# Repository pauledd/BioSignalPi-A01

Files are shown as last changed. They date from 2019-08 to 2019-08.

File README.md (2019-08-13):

# BioSignalPi-A01

Eagle files for the BioSignalPi-A01 egc prototype.  
For application software look at http://martinr89.github.io/BiosignalPI  

NCSA Image

Biosignal PI is licensed by Farhad Abtahi under a Creative Commons Attribution-NonCommercial-ShareAlike 4.0 International License. You are free to:  
    
    Share — copy and redistribute the material in any medium or format
    Adapt — remix, transform, and build upon the material

The licensor cannot revoke these freedoms as long as you follow the license terms.
Under the following terms:

Attribution — You must give appropriate credit, provide a link to the license, and indicate if changes were made. You may do so in any reasonable manner, but not in any way that suggests the licensor endorses you or your use.  
What does "Attribute this work" mean?  
The page you came from contained embedded licensing metadata, including how the creator wishes to be attributed for re-use. You can use the HTML here to cite the work. Doing so will also include metadata on your page so that others can find the original work as well.  

    NonCommercial — You may not use the material for commercial purposes.

    ShareAlike — If you remix, transform, or build upon the material, you must distribute your contributions under the same license as the original.

    No additional restrictions — You may not apply legal terms or technological measures that legally restrict others from doing anything the license permits.

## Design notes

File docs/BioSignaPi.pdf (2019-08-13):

# Software development of Biosignal Pi

An affordable opensource platform for monitoring ECG and respiration

J O N A T A N S N Ä L L

Master of Science Thesis in Medical Engineering Stockholm 2014

II

Software development of Biosignal Pi
An affordable open source platform for monitoring ECG and respiration

Utveckling av mjukvara till Biosignal Pi
En open-source plattform för övervakning av EKG och andning

J O N A T A N S N Ä L L

Master of Science Thesis in Medical Engineering Advanced level (second cycle), 30 credits Supervisor at KTH: Farhad Abtahi Examiner: Mats Nilsson
School of Technology and Health TRITA-STH. EX 2014:100

Royal Institute of Technology KTH STH
SE-141 86 Flemingsberg, Sweden http://www.kth.se/sth

IV

V

Examensarbete inom medicinsk

teknik (HL202X) 30hp

Software development of Biosignal Pi
Technology and Health
Jonatan Snäll
Godkänt 2014-09-30 | Recensent Prof. Kaj Lindecrantz | Handledare Farhad Abtahi
| Uppdragsgivare Dr. Mats Nilsson

## Sammanfattning

För att hantera den ökande kostnaden för hälso- och sjukvård kommer en större del av övervakning samt vård att ske i patientens hem. Det kommer därför att vara önskvärt att utveckla mindre system som är lättare att hantera än de större traditionella apparaterna för att samla in vanliga biosignaler som exempelvis ett EKG.

Detta projekt är en fortsättning på ett tidigare projekt vars syfte var att framställa en ”sköld” som kan kopplas ihop med en Raspberry Pi via dess GPIO pinnar. Det föregående projektet var lyckat och en sköld innehållande en ADAS1000 som kan samla in bl.a. ett EKG samt andningen framställdes.

Syftet med detta projekt var att utveckla en applikation som kan köras på en Raspberry Pi och på så sätt visa den data som samlas in från skölden på en skärm. Det skulle även vara möjligt att spara insamlad data för senare användning. Projektet resulterade i en applikation som uppfyllde dessa krav.

Nyckelord: Raspberry Pi, ADAS1000, Biosignal Pi, EKG

VII

Master of Science Thesis in Medical Engineering (HL202X) 30 credits

Software development of Biosignal Pi
Technology and Health
Jonatan Snäll
Approved 2014-09-30 | Reviewer Prof. Kaj Lindecrantz | Supervisor Farhad Abtahi
| Examiner Dr. Mats Nilsson

## Abstract

In order to handle the increasing costs of healthcare more of the care and monitoring will take place in the patient’s home. It is therefore desirable to develop smaller and portable systems that can record important biosignals such as the electrical activity of the heart in the form of an ECG.

This project is a continuation on a previous project that developed a shield that can be connected to the GPIO pins of a Raspberry Pi, a credit-card sized computer. The shield contains an ADAS1000, a low power and compact device that can record the electrical activity of the heart along with respiration.

The aim of this project was to develop an application that can run on the Raspberry Pi in order to display the captured data from the shield on a screen along with storing the data for further processing. The project was successful in the way that the requirements for the software have been fulfilled.

Keywords: Raspberry Pi, ADAS1000, Biosignal Pi, ECG

IX

## ACKNOWLEDGEMENT

First and foremost I would like to thank my supervisor Farhad Abtahi for the support and guidance throughout the whole project.

I would also like to thank my fellow students Klara Lindskog, Niklas Roos, Lucas Dizon, Martin Johansson and Jing Wang for the constructive discussions during our meetings and for sharing ideas.

I would also like to thank my family for their support and believing in me.

Jonatan Snäll

Stockholm, August 2014

XI

## NOMENCLATURE

## Abbreviations

ADAS | The ADAS 1000 chip
ECG | Electrocardiogram
EDF | European Data Format
GPIO | General Purpose Input/Output
GUI | Graphical User Interface
RLD | Right Leg Drive
RPI | Raspberry Pi
SoC | System On Chip
SPI | Serial Peripheral Interface

XIII

## TABLE OF CONTENTS

ACKNOWLEDGEMENT__________________________________________________________IX NOMENCLATURE______________________________________________________________XI TABLE OF CONTENTS _________________________________________________________XIII

### 1 INTRODUCTION _____________________________________________________________ 1

### 1.1 Background____________________________________________________________________ 1

### 1.2 Objective______________________________________________________________________ 1

### 1.3 Outline _______________________________________________________________________ 2

### 2 THEORETICAL FRAMEWORKS __________________________________________________ 3

### 2.1 Electrophysiology of the heart_____________________________________________________ 3

### 2.2 Raspberry Pi ___________________________________________________________________ 5

### 2.3 GPIO and SPI___________________________________________________________________ 6

### 2.4 ADAS1000 _____________________________________________________________________ 7

### 2.5 Qt Framework__________________________________________________________________ 8

2.5.1 Signals and slots ______________________________________________________________________ 9 2.5.2 Multithreading in Qt__________________________________________________________________ 10

### 2.6 Cross compiling________________________________________________________________ 11

### 2.7 Iterative development __________________________________________________________ 11

### 2.8 European Data Format__________________________________________________________ 12

### 3 METHODS_________________________________________________________________ 15

### 3.1 Requirements and technical goals_________________________________________________ 15

### 3.2 GUI development ______________________________________________________________ 16

### 3.3 Interfacing with the ADAS _______________________________________________________ 16

### 3.4 Data capture__________________________________________________________________ 18

### 3.5 Communication between threads _________________________________________________ 19

### 3.6 Data plotting__________________________________________________________________ 21

### 3.7 Data storage __________________________________________________________________ 24

### 4 RESULTS __________________________________________________________________ 25

### 4.1 Overview of the application______________________________________________________ 25

### 4.2 The ECG capture widget_________________________________________________________ 26

### 4.3 The ECG view widget ___________________________________________________________ 28

### 5 DISCUSSION _______________________________________________________________ 31

5.1 Discussion of the produced application ____________________________________________ 31

5.2 Ethical aspects of using the application ____________________________________________ 32

### 6 CONCLUSIONS _____________________________________________________________ 33

XIV

### 7 FUTURE WORK_____________________________________________________________ 35

### 7.1 Additional features_____________________________________________________________ 35

### 7.2 Future work __________________________________________________________________ 35

### 8 EXPERIENCE GAINED ________________________________________________________ 37

REFERENCES _____________________________________________________________ 39

## 1 INTRODUCTION

### 1.1 Background

An ageing population is an obvious phenomenon in most of the world. An increasing percentage of elderly in the population is mainly caused by a longer life expectancy and lowered fertility rates. Due to the increased percentage of the elderly, higher costs for the healthcare follows [1]. In order to tackle the increasing costs more of the care and monitoring will be performed in the caretaker’s home, this is an increasing trend which will be more common in the future. [2] According to Stockholm country council (SLL) care in the patient’s home is one of their development areas and that it is seen as positive by the patient to receive care outside of the hospital area. [3]

Homecare is usually involving monitoring of the patient and with the current technology a vast number of bio-signals can be measured, such as the hearts electrical activity in the form of an ECG. Due to increasing costs of healthcare and the fact that more of the patient monitoring will take place in the patients home, a low cost and portable system would be desirable. The ADAS1000 (ADAS) is a small and affordable device featuring five-lead ECG digital conversion, lead-off detection and respiration. The ADAS combined with the Raspberry Pi (RPI) which is a small, yet powerful computer, could be an affordable solution.

This project will be a continuation of a previous project that focused on the hardware part, images on the system built in the previous project can be found in appendix C. The conclusions and suggestions for future projects were that the ADAS is a suitable device and that it is possible to connect to the RPI but that the processing power of the RPI was low, thus making it hard to visualize the data in real-time. [4]

### 1.2 Objective

The purpose of this work was to create software running on the RPI that can collect and visualize the biosignals collected from the ADAS.

The goal of this project was:

- Create a way to communicate with existing hardware in order to collect the appropriate bio-signals.
- Visualize collected data in “real-time”
- Store visualized data for further processing later on
- Playback collected data
- Create a suitable graphical user interface (GUI) that can run on the RPI
- Optimum usage of resources considering limited resources of the RPI

### 1.3 Outline

The theoretical framework for the work is presented in chapter 2, followed by the methods used to get the final software in chapter 3. In chapter 4, the results of the work are summarized. Chapter 5 is a discussion where the work will be evaluated. Conclusions from the project are described in chapter 6. Finally, suggestions for future work are presented in chapter 7.

## 2 THEORETICAL FRAMEWORKS

### 2.1 Electrophysiology of the heart

The heart is the primary part of the circulatory system in the human body. The circulatory system consists of three parts, namely, pulmonary circulation, coronary circulation and systemic circulation. The heart acts as a pump, regulating the flow of blood by contracting at different rates. Circulating blood through this system has three main purposes; transportation (e.g. oxygen to the cells, carbon dioxide to the lungs, nutrients), regulation (e.g. body temperature, blood pressure) and protection (e.g. by clotting, carrying antibodies). [5]

The contraction of the heart is triggered by electrical impulses originating from autorythmic fibers, fibers which generate action potentials, in the sinoatrial (SA) node. This node is located in the right atrial wall. Action potentials from the SA node travel through the atrial wall down to the atrioventricular (AV) node and both atriums contracts. When the action potential reaches the AV node it is slowed down in order to let blood flow out of the atriums. From the AV node the action potential travels through the wall between the ventricles in the bundle branches until it reaches the bottom part where it is conducted to the remaining part of the ventricle walls causing a contraction of both ventricles. An illustration of the heart and the conduction system can be seen in Figure 1.

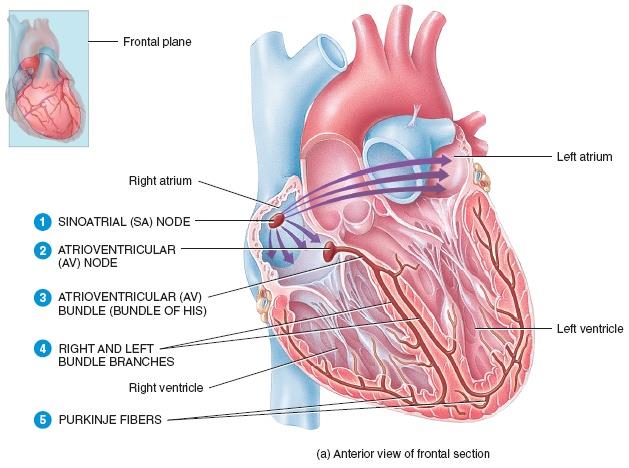
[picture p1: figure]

Figure 1. The heart and its conduction system. [5]

When the action potential goes through the different parts of the heart, small electrical potentials can be measured through the surface of the body. These potentials can be recorded in the form of an electrocardiogram (ECG). Electrodes used to record the ECG are placed on the legs, arms and chest, an illustration of the electrode placement for a 5-lead ECG can be seen in Figure 2.

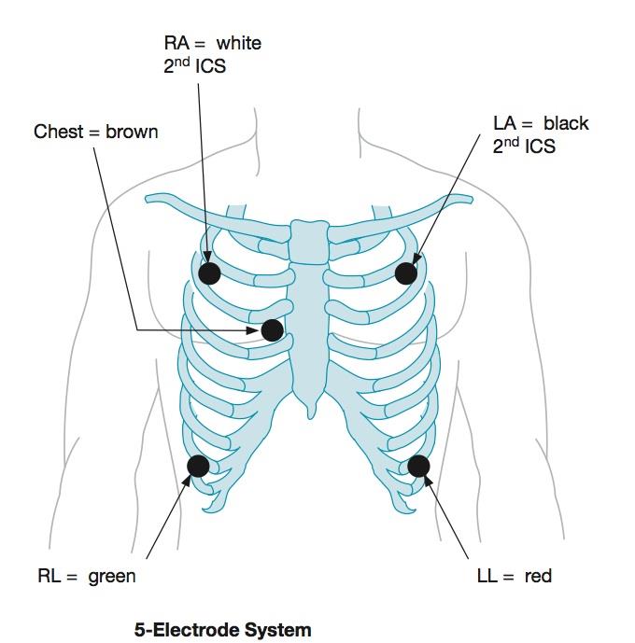
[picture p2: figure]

Figure 2. Electrode placement for a 5-lead ECG. [6]

In a normal ECG three different waves called P-wave, QRS-complex and T-wave exist. An illustration of a typical ECG signal can be seen in Figure 3. The P-wave is seen first as a small deflection, the second part that can be seen is the QRS complex which starts as a downward deflection, the Q part, followed by a larger spike, the R part, and lastly a small downward deflection which is the S part. The third curve that can be observed is the T wave which is a small upward deflection.

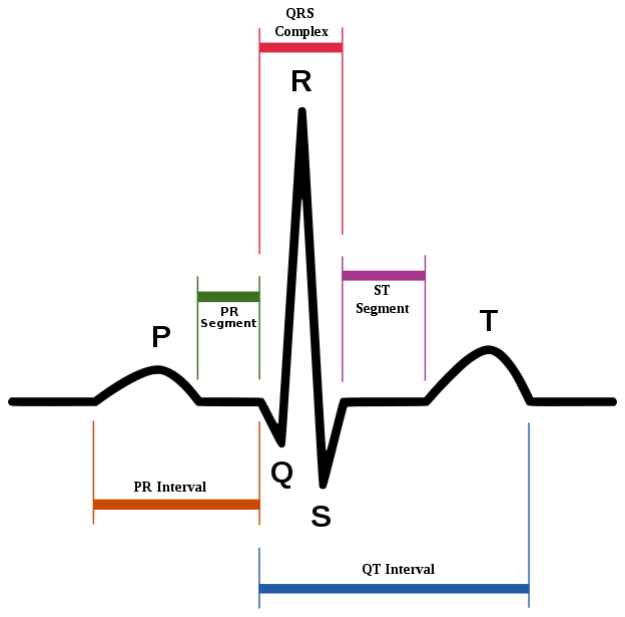
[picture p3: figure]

Figure 3. Illustration of a typical ECG signal. [7]

The different waves in the ECG correspond to specific events in the contraction of the heart making it a useful diagnostic tool for physicians, e.g. an elevated ST segment can indicate a myocardial infarction. [5]

### 2.2 Raspberry Pi

The Raspberry Pi (RPI) is a small credit-card sized computer and is shown in Figure 4. The development of the RPI began in 2006 when the year-on-year decline in knowledge of the students applying to read computer science at the University of Cambridge. In order to inspire young people to experiment more with computers the Raspberry Pi was born.

The RPI has been released in two different versions called model A and model B. The RPI model B (shown in Figure 4) features the BCM2835 system on chip (SoC) from Broadcom, GPIO (general purpose input/output) pins, two USB 2.0 ports, Ethernet, HDMI, RCA video output and a 3.5mm audio output. A detailed comparison between the RPI model A and model B can be found in appendix A.

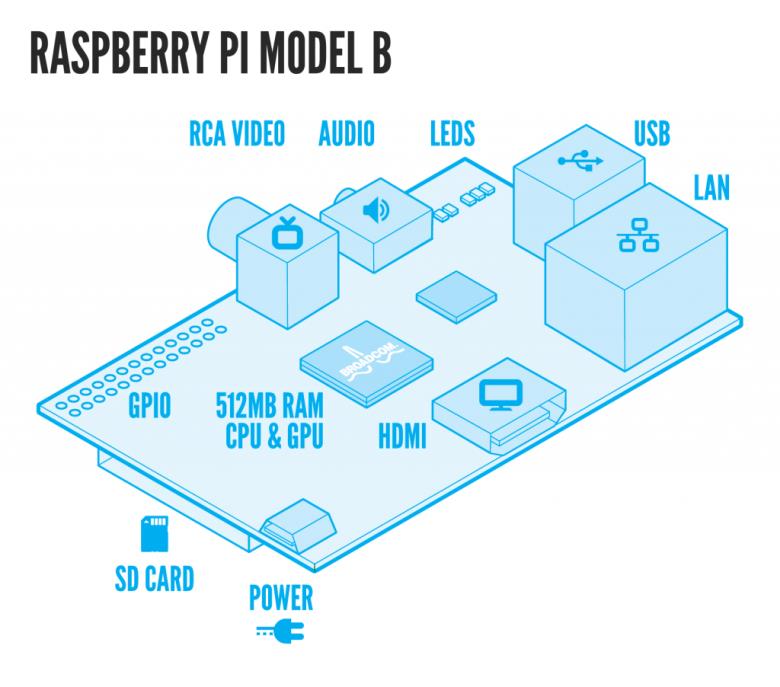
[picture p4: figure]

Figure 4. The Raspberry Pi Model B. [8]

The BCM2835 SoC from Broadcom is used in the Raspberry. SoC is method used to place multiple components on a single chip. The BCM2835 chip used in model B features a 700MHz single-core ARM CPU, GPU, 512MB RAM along with other necessary components needed to run a computer on a single chip.

The GPIO pin layout on the RPI model B can be seen in Figure 5. The GPIO pins on the RPI make it a useful tool for prototyping.

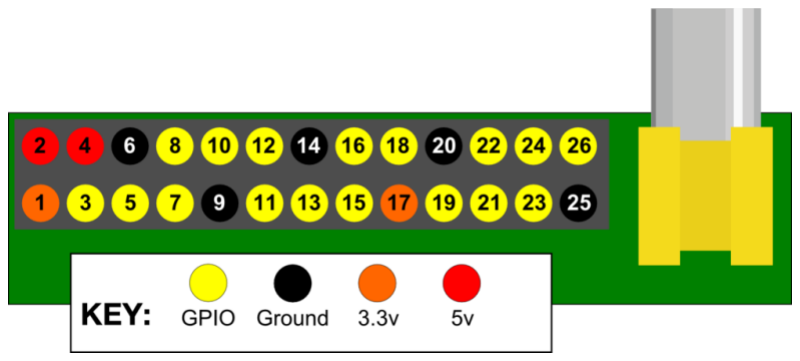
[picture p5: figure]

Figure 5. The RPI Model B GPIO pin layout. [8]

### 2.3 GPIO and SPI

GPIO stands for general purpose input/output, the RPI has seventeen GPIO pins which can be seen as yellow colored in Figure 5. A GPIO pin can be programmed as either an input or an output by the user. [8]

The GPIO pins can also be configured for other functionalities such as I2C and SPI communication. This report will focus on SPI communication so the reader should consult the web for information regarding I2C communication. The GPIO pins have alternative functionalities such as SPI communication [9]. The pins intended to be used in SPI communication are:

- GPIO pin 8 – CE0
- GPIO pin 7 – CE1
- GPIO pin 10 – MOSI
- GPIO pin 9 – MISO
- GPIO pin 11 – SCLK

SPI communication is a protocol used to let a master device communicate with one or multiple slave devices. The SPI communication protocol works by letting the SPI master device control the communication between the master and slave devices. The chip-enable (CE) is normally high when no communication between the SPI slave and master occurs. In order to initiate data transfer the CE is set to low, this enables a specific SPI slave device. When the CE is set to low the clock signal (SCLK) is enabled at a specific frequency, the SPI master then sends data at the “master out – slave in” (MOSI) line and samples the signal on the “master in – slave out” (MISO) line. This means that in order to receive information from a SPI slave device, the same amount of bits have to be sent by the SPI master device. An illustration on how the SPI master communicates with one or multiple slave devices can be seen in Figure 6. [10]

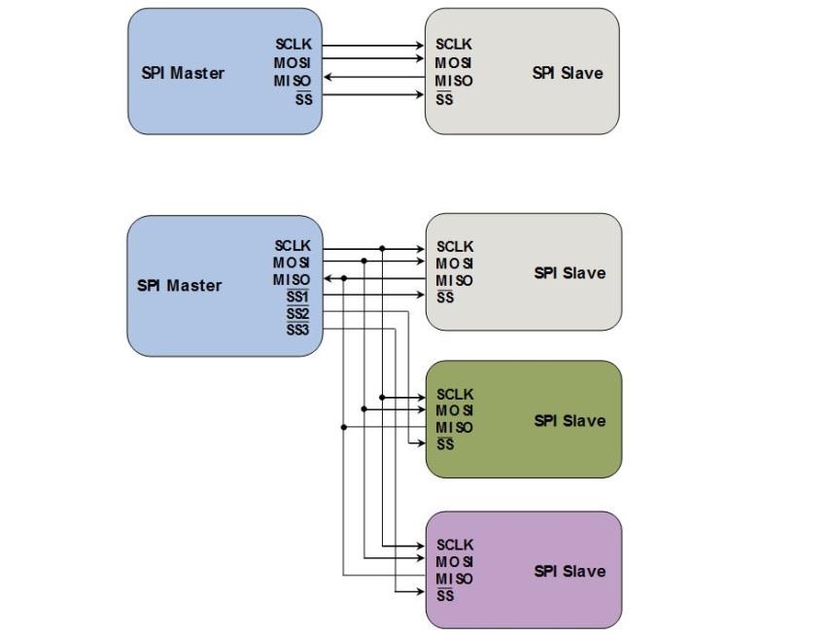
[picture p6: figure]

Figure 6. Illustration on how a SPI master device is connected to one or multiple slave devices. [10]

SPI communication can be done in four different modes. The difference between the modes is when the MOSI is turned on or off. The mode is set by changing the clock polarity (CPOL) and the clock phase (CPHA). An illustration of the different SPI modes can be seen in Figure 7.

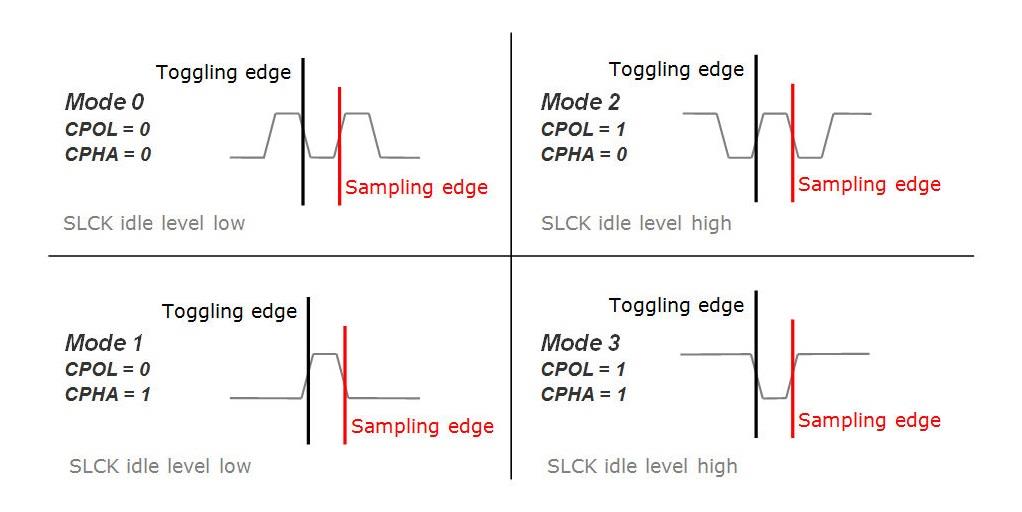
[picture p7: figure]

Figure 7. Illustration of the different SPI modes. [10]

### 2.4 ADAS1000

The ADAS1000 (ADAS) is an analogue front-end system aimed to simplify the development of monitoring and diagnostic medical devices that need to acquire ECG signals. The ADAS device features a five lead ECG system along with the ability to measure thoracic impedance and detect pacing artefacts. ADAS can also be configured to operate in either low power mode or low noise mode depending on the requirements of the application for the device. The ADAS is available in nine different models with different features, such as different numbers of input channels, right leg drive, shield drive, pace detection, respiration and lead off detection. [11] [12]

The ADAS have 5 input ECG channels¹

, three of them are the Lead I, Lead II and Lead III channels and the other two is the V1 and V2 channels. The V1 and V2 channels can be configured to work as either ECG input or perform other measurements. An example of lead compositions and how they are calculated can be seen in Table 1.

Table 1. Lead composiotions for the ADAS ECG inputs. [12]

Lead name | Composition
Lead I | RA-LA
Lead II | LL-RA
Lead III | LL-LA
Respiration | RA-LA

Another important feature that the ADAS has is the ability to detect whether the leads are connected or not. There are two methods to this, the first method is by injecting a

1 Some models of the ADAS have only 3 input channels.

DC current and the second method injects an AC current into the leads. The two methods can be used separately or work together.

In the DC lead off detection method a connected electrode produces a small voltage shift, if the electrode is disconnected a larger voltage shift will occur which is detected. The DC lead off detection has a delay between disconnection of electrode and detection, this delay is approximately:

The AC lead off detection works by measuring the change in voltage and compare it to a programmable upper and lower threshold. The frequency of the injected current is above 2 kHz and is therefore removed in the internal filters in order to not interfere with the ECG signal. The delay between disconnection of electrodes and detection for the AC method is below 10 ms.

Some of the ADAS models have the respiration feature which works by injecting a high frequency current through two electrodes and measuring the impedance variation caused by breathing. The frequency of the injected current can be programmed to be between 46.5 kHz to 64 kHz. The respiration can be measured through either the ECG leads or through the external pins dedicated to respiration measurement, respiration can only be measured through one path at a time.

### 2.5 Qt Framework

Qt is a cross-platform application framework using standard C++.In addition, multiple bindings of this framework to other programming languages exist. Development of Qt was started in the 1990's and has since then grown in popularity and is now widely used around the world, thus making it a good platform to build applications on. [13]

Qt is available under two different licenses; a commercial one maintained by Digia and as open-source available under the GNU GPL (GNU General Public License) 3 and GNU LGPL (GNU Lesser General Public License) version 2.1 [14]. The GNU GPL and GNU LGPL allow Qt to be used in both “free software” and commercial solutions. [15] [16]

A basic Qt GUI application consists of a mainwindow and a QApplication object. The QApplication handles the application-wide resources along with the event-loop of the application. After all components of the application are initialized the applications event-loop should be entered, the event loop is a state where the application can idle and wait for events such as a pressed button or a timer event. The mainwindow contains all the components of the application, also called widgets (window gadgets). A widget is a visual element e.g. button or label. The widget may also contain other widgets for further flexibility. An example of a nested widget is a widget containing a knob and a label that displays the current value of the knob. [13] Figure 8 illustrates how a widget can contain multiple widgets.

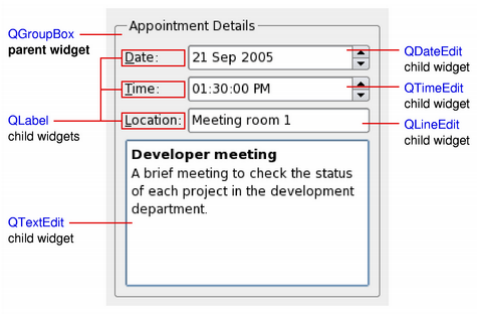
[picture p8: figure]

Figure 8. Example of a Qt widget containing other widgets. [17]

### 2.5.1 Signals and slots

In a normal application objects want to be able to communicate with each other, an example could be when a push button in the application is pressed the user usually wants to perform some action. The signal & slot mechanism makes this an easy task.

Classes or subclasses that inherit QObject can use signals & slots by adding the Q_OBJECT macro to the header file. A signal and slot is connected by the following syntax:

QObject::connect(sender, signal, receiver, slot)
Widgets usually have pre-defined signals and slots but it is common to subclass widgets in order to add custom signals or slots. Subclassed widgets inherit the signals & slots from the base widget.

Signals & slots are loosely coupled which means that an emitted signal does not have to be connected to a slot and a slot does not have to be connected to a signal. As a result it is easy to create independent components.

A signal can be seen as a function call and a slot can be seen as a normal function. A signal can be connected to multiple slots and multiple signals can be connected to a single slot. Signals do not even have to be connected to a slot, a signal can be connected to another signal. An illustration on how signals and slots can work within an application can be seen in Figure 9. [18]

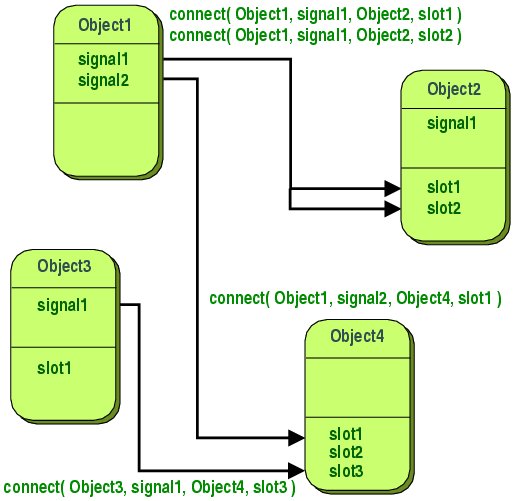
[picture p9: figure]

Figure 9. Example of how objects can communicate with each other through the signal-slot mechanism. [18]

### 2.5.2 Multithreading in Qt

A thread and a process are two different things, a process can be an application running on the computer, for example a web browser. Multiple processes can be running at the same time, which is called multitasking. Sometimes it is also needed to achieve the same thing within a single process, for example when a large file needs to be saved without locking the GUI of an application. This is also called concurrency – doing multiple tasks simultaneously. [19]

Threads can be used to achieve concurrency within a process, like in the previous example the GUI can have one thread and a worker thread can be created to save the file. The difference between a process and a thread is that different processes do not share the same memory with each other, threads within a process do however share the same memory.

Stating that processes or threads are running at the same time is not always true. True concurrency is only possible in processors with multiple cores. If multiple processes or threads are running on the same core the fact that they are running simultaneously is merely an illusion, the processor is quickly interrupting each process or thread and moves to the next process or thread. The jump from one thread or process to another can occur at any time.

As previously mentioned, threads within a process share the same memory, this can be both good and bad. The fact that they share the same memory makes it fast to jump between the threads and to access shared data. But it is also important that the integrity of the data is preserved when a reference to the same object exists in two or more threads. An illustration on how threads and processes are stored in the memory can be seen in Figure 10.

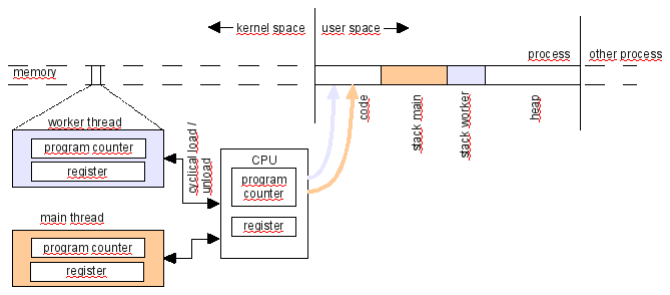
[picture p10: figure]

Figure 10. Illustration on how threads and processes are stored in the memory. [19]

There are multiple methods that can be used to preserve the integrity of data available in multiple threads, some of them are mentioned below. [20]

- Using a mutex to lock and unlock data
- Using semaphores to protect multiple resources
- Using the Qt event system

In the case where a GUI thread and a sampling thread is used an easy way to exchange data is by using the built in Qt event system by utilizing the signal & slot mechanism. It is important to remember that a queued connection has to be established because that will place the task in the receivers thread event loop and let it finish its current task. [21] [20]

### 2.6 Cross compiling

A cross compiler is a compiler that is able to produce executable code for a different platform than the one the compiler is running on. For instance, compiling an application on the RPI would take much longer than cross compiling the same application on a PC.

A complete guide on how to build Qt 5 in order to cross compile projects for the RPI can be found in appendix B.

### 2.7 Iterative development

One of the goals with iterative development is to break down a bigger project into smaller pieces that are easier to handle. Iterative development can also be combined with other software development methodologies such as the waterfall development process. The waterfall development process also breaks down the project into smaller pieces that follows each other. [22]

The iterative development process is a combination of the Rational Unified Process (RUP) and eXtreme Programming (XP). This means that the resulting software is tailored for the target and at the same time it is tested and easily maintained by following the RUP and XP development methodologies. [23]

Figure 11 illustrates a small piece of the final product which consists of multiple similar pieces. Each piece is first planned in order to identify requirements and then a first implementation is performed. The piece of software is then tested and evaluated in order to see if the initial requirements are fulfilled. If they are not, the process is repeated until the requirements are fulfilled. [22] [23]

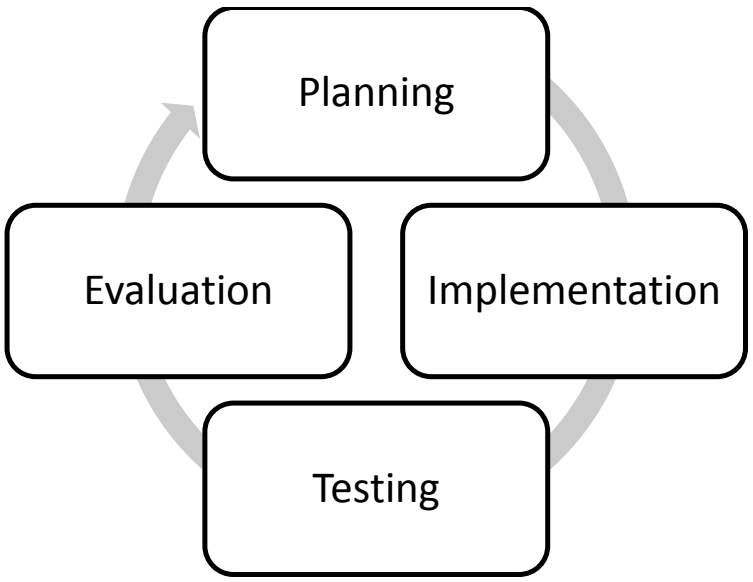
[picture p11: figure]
Planning; Implementation; Testing; Evaluation

Figure 11. The iterative process used in this project.

### 2.8 European Data Format

The European Data Format (EDF) is a file format that can store bio-signals from multiple channels in a single file. It has existed since 1992 and is a common file format for researches that work with EEG or PSG (polysomnography) recordings.

The EDF file format contains a variable header and data record, the header contains 256 bytes for recording information and an additional 256 bytes for each signal, the structure of the header can be seen in Table 2. The rest of the file contains a number of data records, the duration of a record and the number of samples in each record for each signal is specified in the header corresponding to the specific signal. This means that the signals in the file do not need to have the same sampling frequency. An ECG signal could for example be combined with an ICG, EEG or body temperature signal with a different sampling frequency. The structure of a data record can be seen in Table
3. [24]

Table 2. Data header of an EDF file.

Version | 8 ascii
Patient identification | 80 ascii
Recording identification | 80 ascii
Startdate of recording | 8 ascii
Starttime of recording | 8 ascii
Number of bytes in header record | 8 ascii
Reserved | 44 ascii
Number of data records | 8 ascii
Duration of data record (s) | 8 ascii
Number of signals (ns) | 4 ascii
Label | ns*16 ascii
Transducer type | ns*80 ascii
Physical dimension | ns*8 ascii
Physical minimum | ns*8 ascii
Physical maximum | ns*8 ascii
Digital minimum | ns*8 ascii
Digital maximum | ns*8 ascii
Prefiltering | ns*80 ascii
Nr. of samples in each data record | ns*8 ascii
Reserved | ns*32 ascii

Table 3. Data record of an EDF file.

First signal | Nr of samples[1]*integer
Second signal | Nr of samples[2]*integer
… | …
Last signal | Nr of samples[ns]*integer

## 3 METHODS

### 3.1 Requirements and technical goals

During the software requirement analysis it is determined what the software has to do, not how the software performs a specific task. It is important to identify requirements of the software early on in the project, because adding more requirements later on will increase both time required and cost compared to if the requirement was stated at the start. A list of requirements for the software can be seen in the list below. [25]

- Collect data from the ADAS
- Store collected data
- Visualize sampled data in real time and from file
- Be able to collect data at different rates
- Lead-off detection

In addition to the features listed above the produced software also had to be efficient, testable, readable and modular. The software should also be flexible, reusable and easy to maintain. [25]

The software had to be efficient enough so it could both collect and visualize the data at the same time. Efficiency can be achieved by writing time critical parts of the software in a lower level language such as C or assembler, or even better, use existing and already tested libraries.

The ability to test the software is also an important quality. A way to perform such tests is to use the built in test tone generator in the ADAS and see if the data conversion and data visualization is correct. The ADAS can also tell if frames are missed or being read too slowly, thus efficiency of the program can also be tested. Lastly, the ADAS can also perform tests on the device itself in order to check if it is functioning correctly.

The code written for the software should be readable by writing code that in itself tells the programmer how the application works. Unclear parts of the code should not exist but in case there is, comments should be used to avoid errors. Code is made modular by following the object oriented programming (OOP) paradigm. This way the software could be divided into small modules that can be changed and tested on their own. This means that a module can also be easily changed to another one, for example; the communication with the ADAS is a module, if another device is used it is easy to change only that part without changing the rest of the software.

The software is also flexible and reusable by using the cross-platform Qt framework. This means that the software could easily be recompiled and deployed in another

environment²

. In order to deploy the software of this project in another environment it is important to take the SPI-communication library into account because it is platform specific for the RPI.

### 3.2 GUI development

A central part of the application is the GUI which is what the user will see and interact with. Therefore it was important to make the interface easy to use but also easy to modify in order to add more features to future versions of the application.

The structure of the GUI was changed multiple times during the development cycle as a part of the iterative process. The final version of the GUI contains a main window which will hold all the graphical components of the application.

In order to create a GUI that could easily be modified a StackedWidget was used to hold the different views of the application. A StackedWidget works by placing widgets on top of each other and giving them specific ID’s. The user can then call the SetCurrentIndex method with an ID as an argument in order to view a specific widget.

### 3.3 Interfacing with the ADAS

The ADAS is controlled by SPI, this will enable the program to configure registers and read data frames. SPI communication with the ADAS can be implemented in several ways but the BCM2835 C-library was used in this project for the sake of simplicity.

The BCM2835 C-library provides easy access to the low level peripherals of the RPI, for example the GPIO pins. The library also includes functions for SPI and I2C communication. [26]

Before setting up the SPI the ADAS had to be reset, this was done by setting the ̅̅̅̅̅̅̅̅̅ line to low and wait for the device to reset, the ̅̅̅̅̅̅̅̅̅ line was then set to high.

In order to set up the SPI port the following parameters need to be set:

- Bit order
- Data mode
- Clock divider

The bit order of the ADAS is most significant bit (MSB) first. The different data modes were shown in Figure 7 and the ADAS requires that mode 0 is used, which is CPOL and CPHA is 0. The clock divider is used to set SCLK, the required speed can be calculated by using the equation below.

( )

The SCLK was set to 488 kHz which is enough for all configurations used in this project.

2 The fact that the software can be deployed in another environment by just recompiling is not true in general. There may be platform specific libraries used in software that must be taken into account before deploying the application on another platform.

Two different operation modes were implemented, the first was the ECG mode and the other one used the built in test tone feature for testing purposes. In order start framing a number of write commands has to be sent to the ADAS. The write commands for the ECG and test tone mode can be seen in Table 4 and Table 5. The last write command addressing FRAMES tells the ADAS to start framing. A write command consists of 32 bits, the first bit is set to 1 for write or 0 for read, the next 7 bits are the control register address and the remaining 24 bits are the data. An example on what a normal write command to the ADAS looks like is shown in Table 6. It is also possible to read control registers. In order to read a register the first bit has to be set to 0 followed by the control register address and 24 unused bits. The ADAS will then output the data of the register in the next frame. Reading a register will cause the ECG framing to stop so a new framing command has to be sent after reading. A visualisation on how the SPI communication is implemented can be seen in Figure 12.

Table 4. Register commands to configure ADAS to output ECG frames.

Register addressed | Write command
CMREFCTL | 0x85E0000A
FILTCTL | 0x8B000000
FRMCTL | 0x8A1FCE00
LOFFCTL | 0x82000015
ECGCTL | 0x81F800AE
RESPCTL | 0x83002099
FRAMES | 0x40000000

Table 5. Register commands to configure ADAS to output ECG frames using the built in test tone.

Register addressed | Write command
CMREFCTL | 0x85E0000B
TESTTONE | 0x88F8001D
FILTCTL | 0x8B00001D
FRMCTL | 0x8A1FCE10
ECGCTL | 0x81F800AE
FRAMES | 0x40000000

Table 6. Example of a write command to the ADAS.

32 bit write command | R/W | Register address | Data
0x85E0000A | 1 | 0000101 | 111000000000000000001010

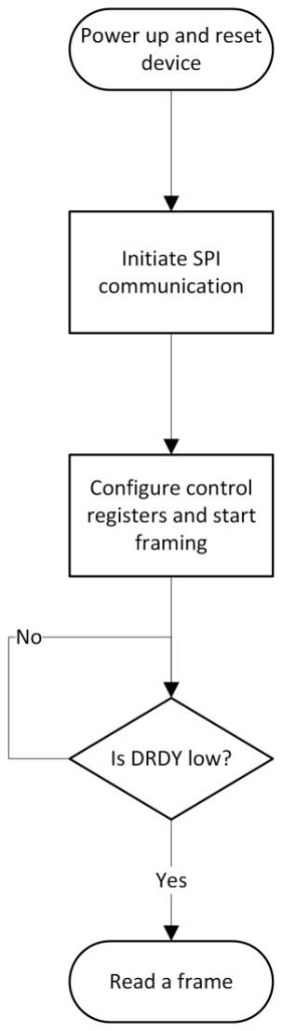
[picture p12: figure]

Figure 12. Flowchart of how the SPI communication is implemented.

### 3.4 Data capture

The sampling of data is performed in its own thread in order to prevent locking of the GUI. Before the sampling process is started the settings are read and the operating mode is selected. The sampling thread then tells the class communicating with the ADAS which mode is selected and the correct control registers are set.

When the settings are applied, the sampling loop is entered, which will collect samples in a specific time interval, determined by the sampling rate. When a sample is collected it is stored in the memory, the samples are also decimated in order to make the plotting faster. The loop will stop collecting samples when it receives a signal from the GUI thread that tells it to stop.

Samples collected are first stored in a text file but they can also be saved in the EDF file format. More information on how the samples are saved can be found in section 3.7. A visualization of the whole sampling process can be seen in Figure 13.

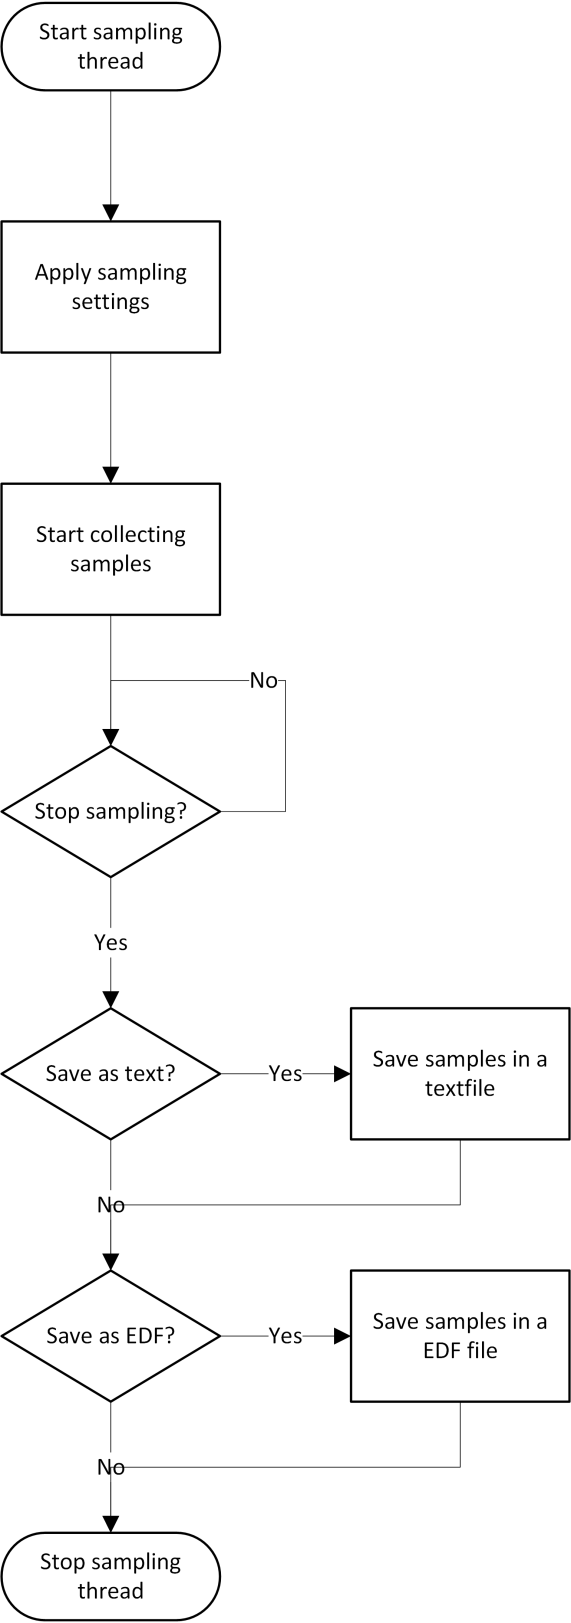
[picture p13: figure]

Figure 13. Illustration of the sampling process.

### 3.5 Communication between threads

Communication between the sampling thread and the GUI thread is an important part of the application. The important part was that it had to be thread safe, this was achieved by using the signal & slot feature that Qt offers. An illustration on how the GUI thread communicates with the sampling thread during collection of data can be seen in Figure 14.

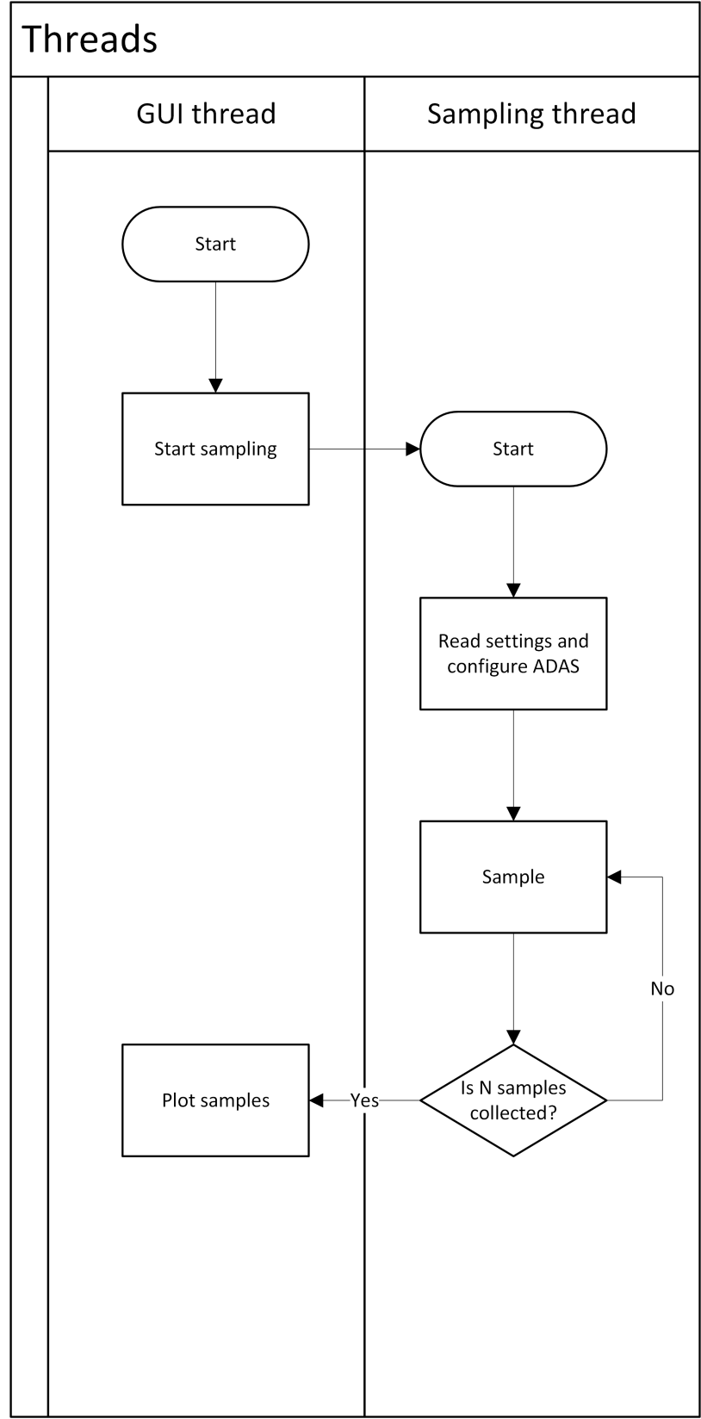
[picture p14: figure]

Figure 14. Flowchart on how the GUI thread communicates with the sampling thread during data collection.

In order to reduce the number of signals from the sampling thread a number of samples were saved in an array before they were sent to the GUI thread with a signal. The format of the emitted signal was QVector<QVector<QPointF>>>.

The signal & slot mechanism was made thread safe by using a queued connection which means that the signal is placed in the GUI threads event loop and letting the GUI finish its current task before the slot is invoked. Because a queued connection was used a new type had to be registered. How to register a new type can be seen below.

qRegisterMetaType< QVector<QVector<QPointF> > >("QVector<QVector<QPointF> >")

### 3.6 Data plotting

An important part of the application was to visualize the recorded biosignals from the ADAS in “real-time”, which means that performance is an important aspect. Another important part was that the plotting should also be easy to implement and maintain.

In order to evaluate the performance of the plotting method a text file with pre-recorded samples was provided. From the pre-recorded samples 5000 values were loaded and in order to further simulate how the plotting would work in real-time, a decimation of the samples was performed as well.

Initially the QwtPlot class was used which have a method called SetRawSamples that stores samples as a vector and the next time the Replot method is called the plot canvas will be redrawn with the samples stored. This method proved to be too resource costly and the system could only handle one plot on a small screen (due to a smaller plot area) using all the systems resources. A flowchart of the initial plotting method described above can be seen in Figure 15.

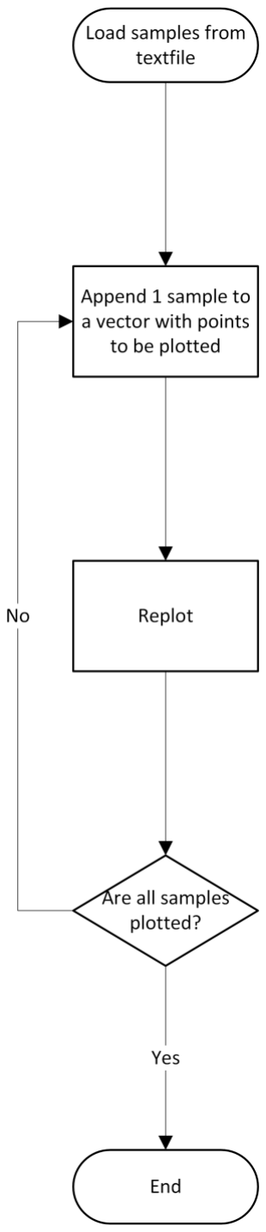
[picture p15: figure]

Figure 15. Initial plotting method

Instead of using the plotting method mentioned above a new plotting method had to be implemented, capable of plotting the collected samples fast while using a small amount of system resources. The solution was to write a custom plotting class that re-implemented the QwtPlot class. The plot starts with an empty canvas and a DirectPainter is used to draw the curve segments. This means that the plot canvas only have to be redrawn when the plot has to be cleared which occurs when the plot curve reaches the end of the canvas, how often the plot has to be cleared depends on the scale on the x-axis which was set to 10 s. A flowchart of the improved plotting method can be seen in Figure 16.

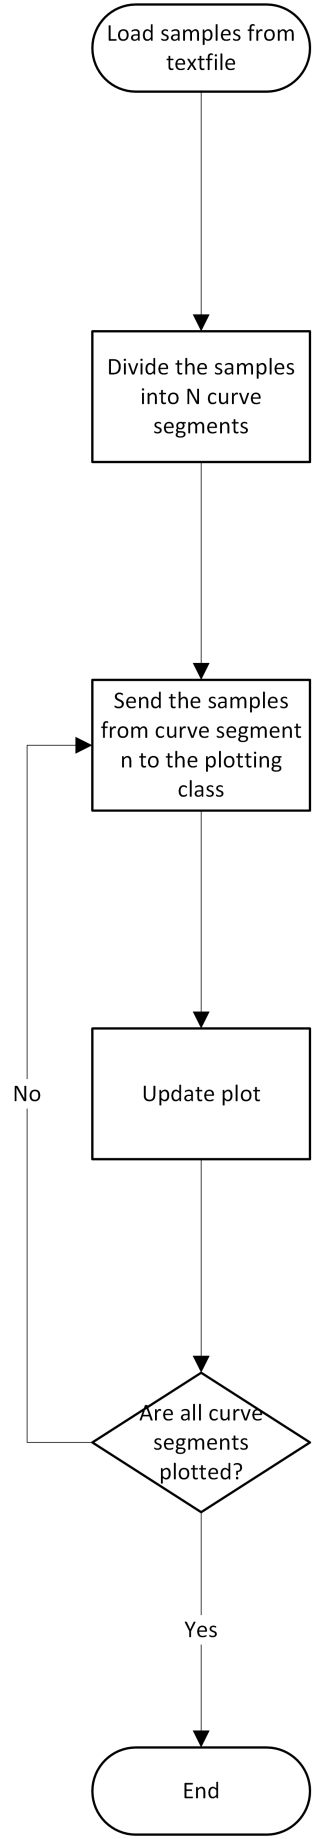
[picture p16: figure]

Figure 16. Final plotting method.

### 3.7 Data storage

During runtime the samples are stored in the memory of the RPI as a vector and when the user chooses to end the recording the samples are stored in two text files (a header and data file) and optionally an EDF+ file.

The header of the text file contains useful information about the recording such as filename, samples in file, duration of the recording, sample rate, source signal and patient information. The data file holds one sample on each row separated by a tab.

The EDF+ file uses the edflib, a C-library, to create a valid EDF file that can be viewed in any EDF compatible software such as the EDF browser.

## 4 RESULTS

A Qt-based application running on the RPI has been produced. It can collect and view an ECG along with respiration in real-time and also view an already recorded ECG. Below follows a more thorough description of the software and a guide on how to use the software can be found in appendix D.

### 4.1 Overview of the application

As described in section 3.1 the GUI consists of a stacked widget, a snapshot button, a quit button and navigation bar. The stacked widget contains a widget for the starting screen, a widget for capturing an ECG, a widget for viewing an ECG and finally a settings widget.

The starting screen of the application can be seen in Figure 17 which contains short instructions on how to use the software and an image showing the recommended electrode placement.

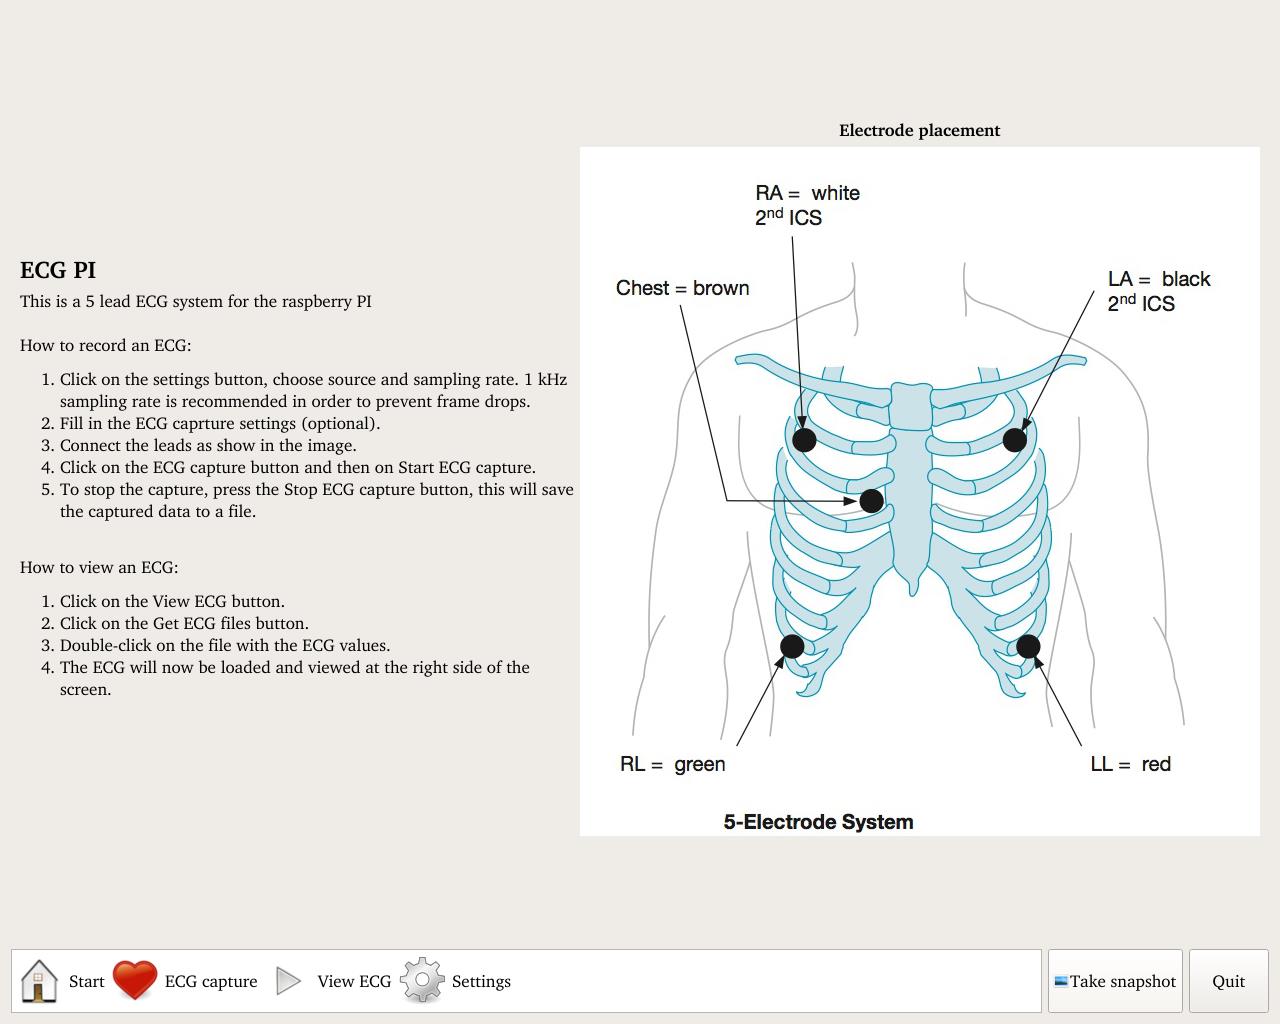
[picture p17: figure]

Figure 17. The starting screen on the BiosignalPI application.

By using the navigation bar below the stacked widget, the user can navigate between the different widgets, the ECG capture and ECG view will be explained in detail in section 4.2 and 4.3 respectively.

On the settings screen of the application the user can choose signal source and sample rate along with a number of optional parameters which can be seen in Figure 18.

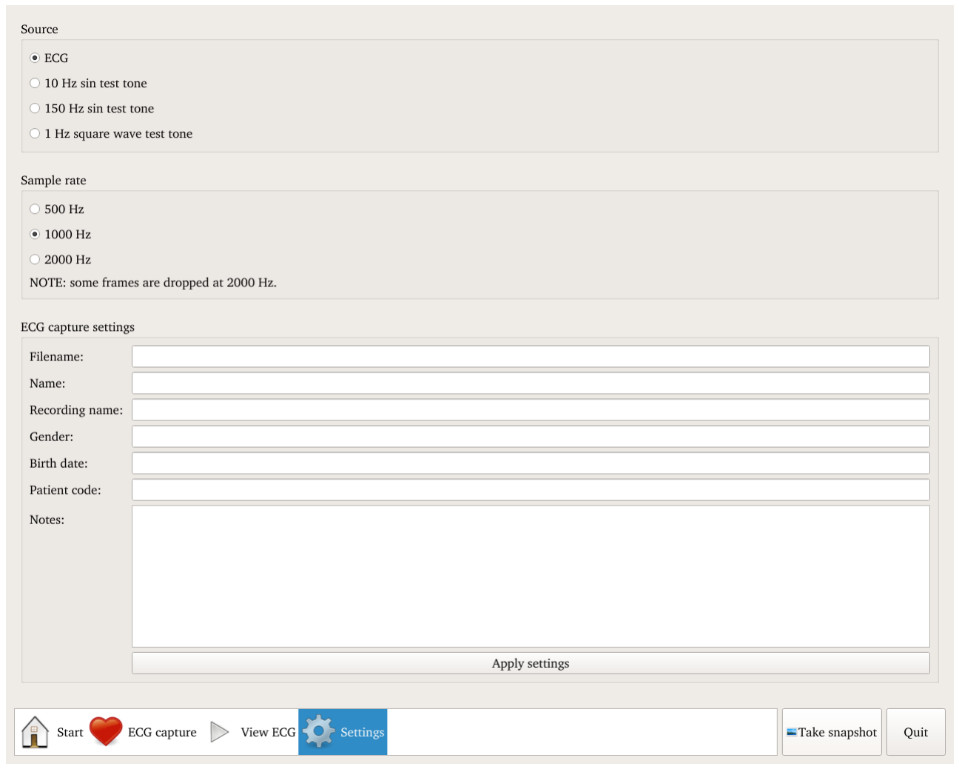
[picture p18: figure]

Figure 18. Settings screen of the application.

### 4.2 The ECG capture widget

The ECG capture widget which can be seen in Figure 19 consists of a button row which contains buttons to start and stop a recording, a status bar and four plots that displays the collected data in real-time.

The status bar is used to give the user information about what the application is doing, during sampling the status bar notifies the user if the leads is disconnected by using the lead off detection feature on the ADAS.

An example on what the ECG capture widget looks like during sampling can be seen in Figure 20.

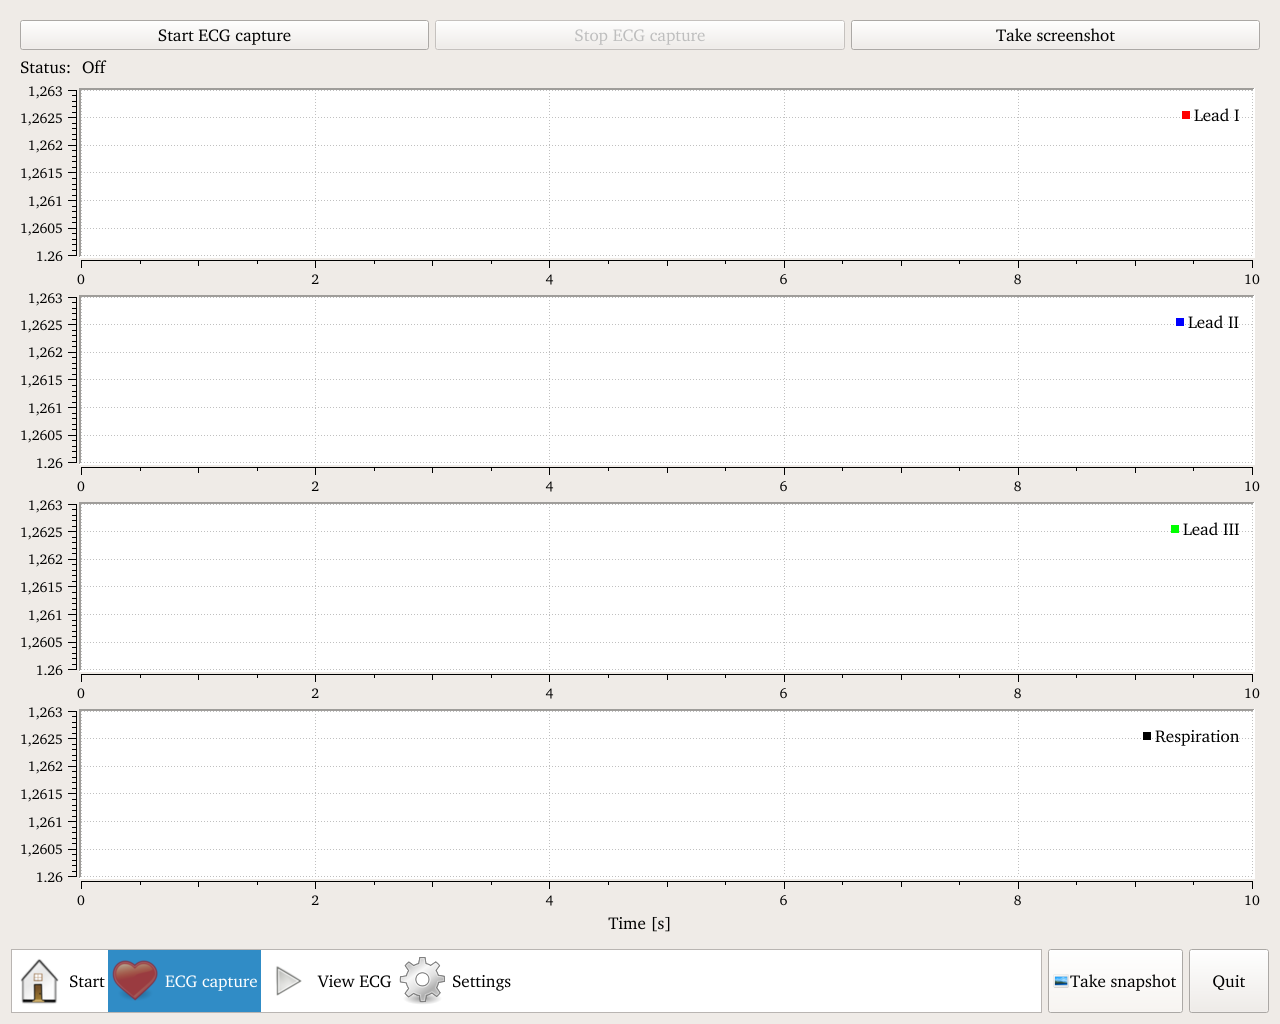
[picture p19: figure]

Figure 19. ECG capture screen of the application.

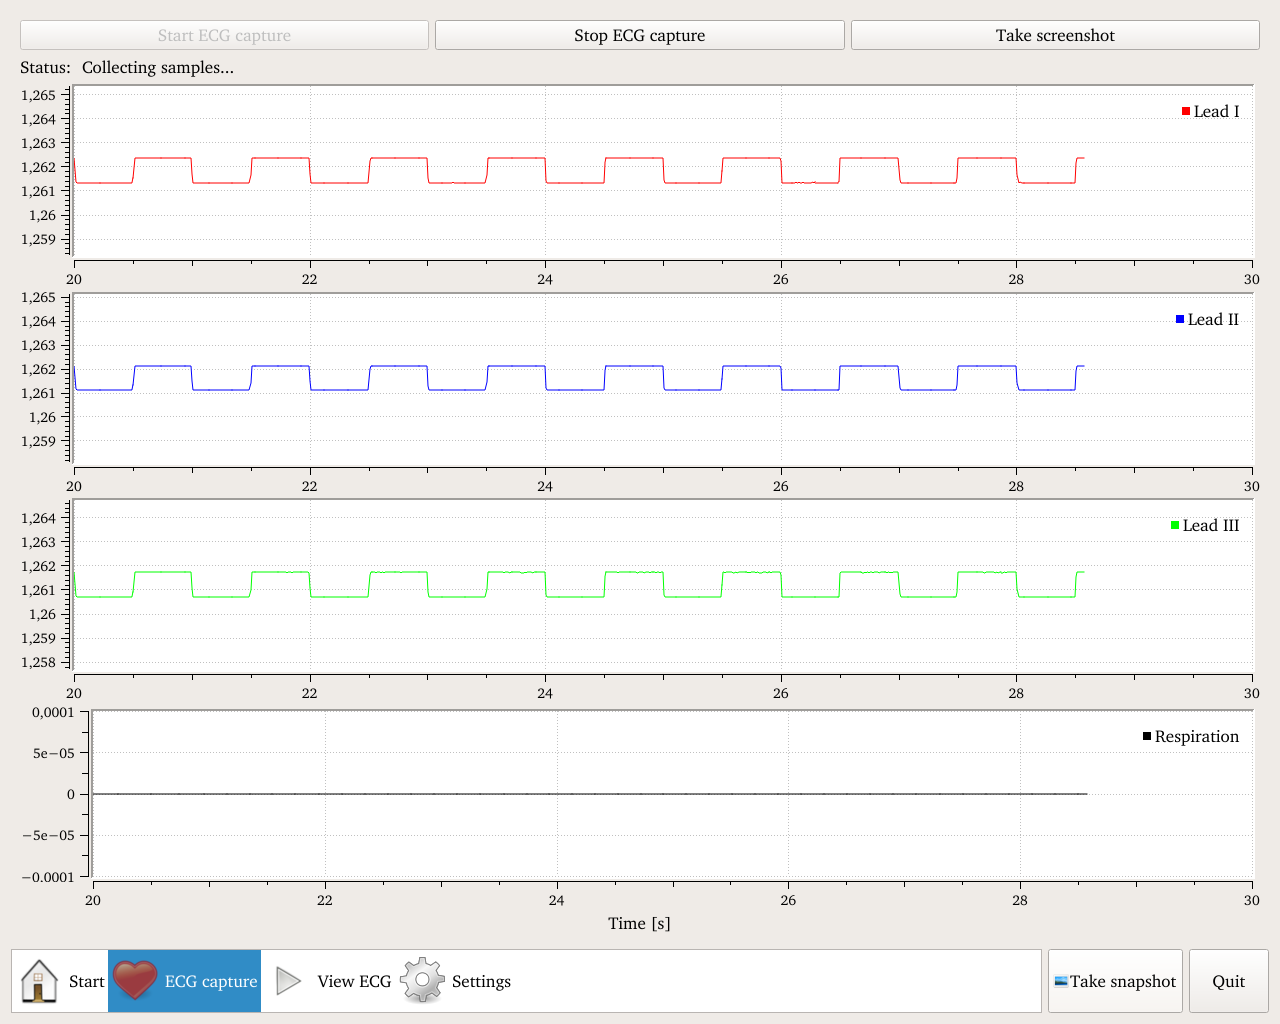
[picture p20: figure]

Figure 20. ECG capture running with the 1 Hz square wave option.

### 4.3 The ECG view widget

The ECG view widget is divided into two sections, a left section containing buttons and information and a right section containing the plots and navigation controls. Snapshots of the ECG view widget can be seen in Figure 21 and Figure 22.

The user can click on the “Get ECG files” button to show a list of supported files in the box below. In order to view an ECG the user has to double click on the desired data file. When a file is selected the application will show the ECG header in the box below the window size control. An example of what a header contains can be seen in Figure 22. When the header is loaded the application will start to read the data file in a separate thread in order to prevent locking of the GUI. When the data is loaded into the memory it will be plotted on the right hand side of the screen which can be seen in Figure 22. Finally the user can set the window size which controls the scale on the x-axis in the plots.

In order to navigate through the data the user can use the slider below the plots, the scroll wheel on the mouse or by clicking on the arrows on the right and left side of the play and pause buttons. The user also has the option to playback the recording in real-time by pressing the play button, the speed is depending on what window size that is selected.

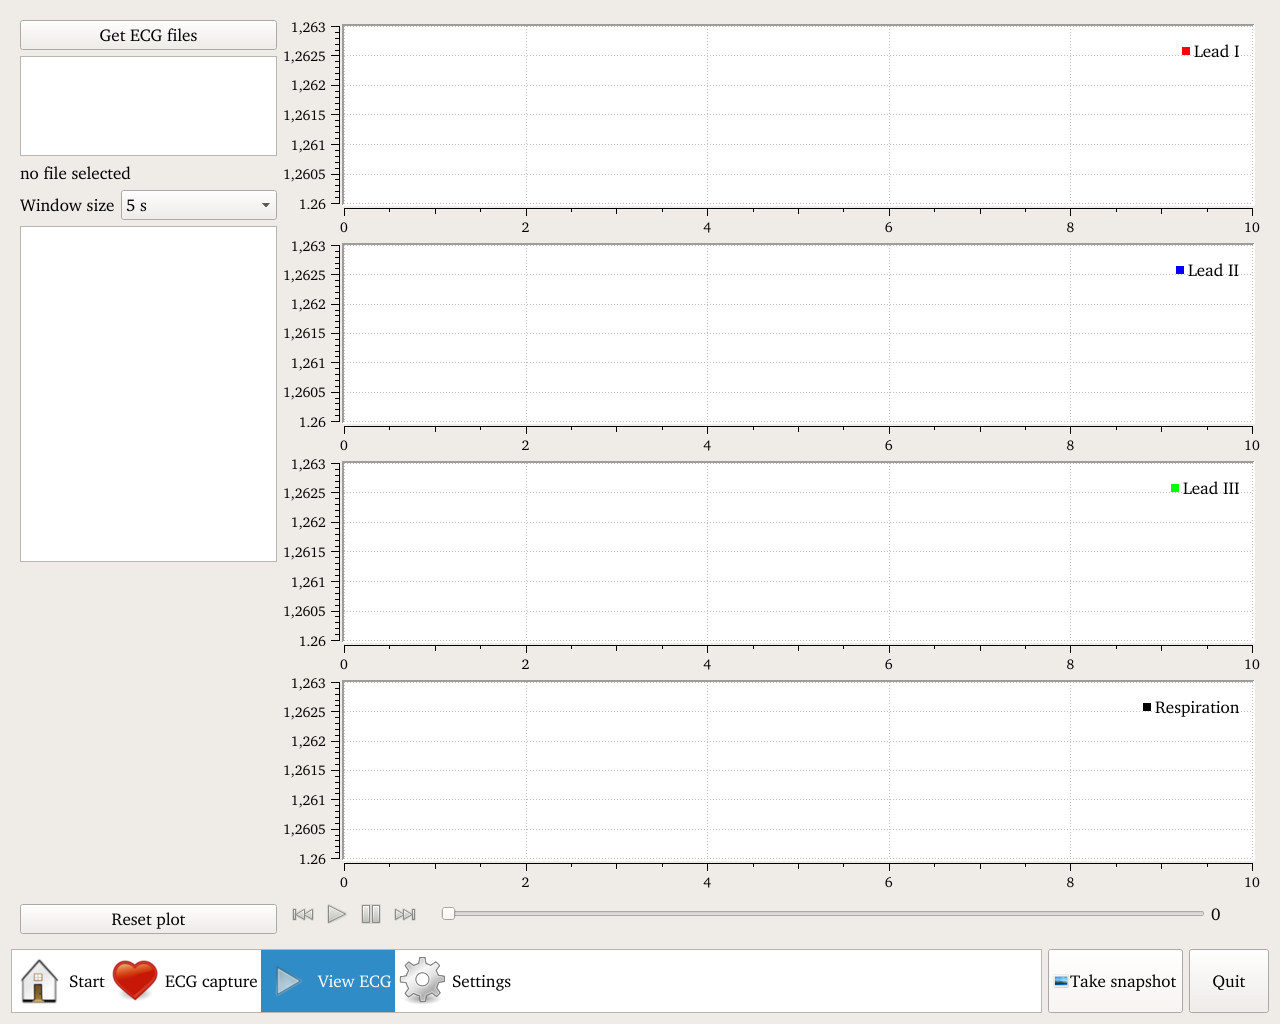
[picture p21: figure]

Figure 21. The view ECG screen of the application.

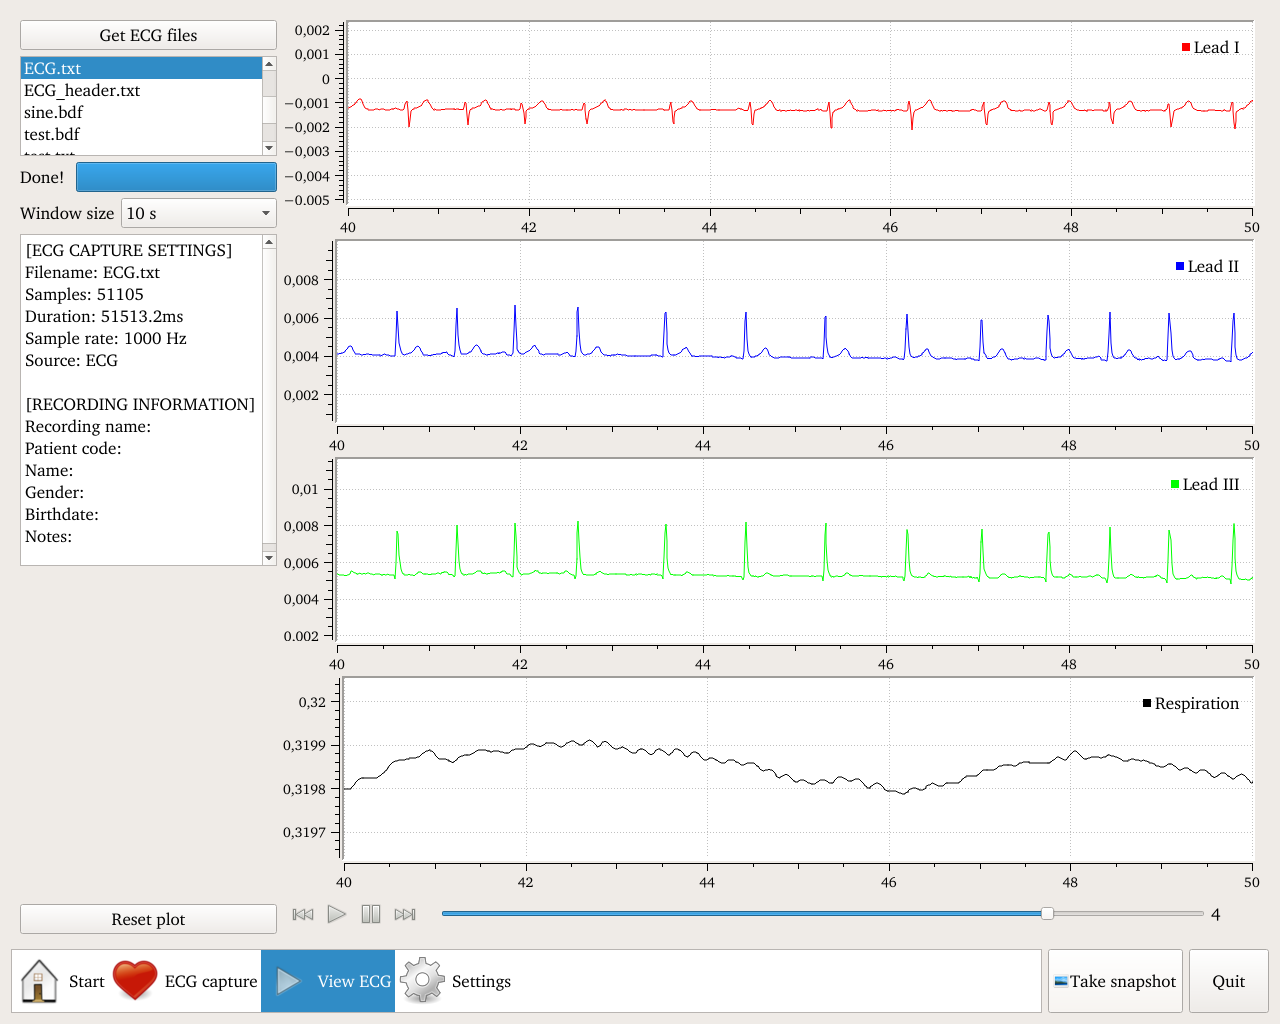
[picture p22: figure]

Figure 22. View of a recorded ECG.

## 5 DISCUSSION

### 5.1 Discussion of the produced application

As described in section 3.3 (interfacing with the ADAS) and according to the requirements from section 3.1 a way to interface with the existing hardware have been developed. The communication with the hardware uses the BCM2835 C-library which is the only platform specific library used in this project. It is therefore easy to rewrite the class communicating with the hardware if the user wants to change platform due to the modularity of the software which was one of the requirements listed in section 3.1.

Data can also be seen in real-time due to the reimplementation of the QwtPlot class utilizing the QwtPlotDirectPainter because replotting every time samples were received in the GUI thread would be too expensive.

Collected data can be stored in two different formats through the software, either as a plain text-file or as an EDF+ file. Providing the option to save the file in multiple formats makes the system flexible because tools already exists that can handle EDF+ files for instance. The text-file can easily be imported to MATLAB, a powerful and widely used tool, for further processing.

The fact that there already existed a C-library for storage in the EDF+ file format made it easy to implement. Tests were made and it was visually confirmed that the data was stored correctly by comparing the same data plotted in MATLAB and in the edfbrowser, software that can visualize EDF+ files.

A way to playback collected data was also implemented, the functionality to do this requires the text file header and the data. When the user selects a file by double clicking on it the filename is sent to a class running in a separate thread. The loading of the data file is running in a separate thread because having it in the same thread as the GUI would lock both the GUI and the cursor until the file was completely loaded. A progress bar is also visible to indicate that the file is loading.

The interface of the software is visible in Figure 17, the idea behind the layout was ease of use but also to utilize the screen area in the best way possible. The navigation bar on the bottom of the screen contains both icons and text making it clearer an easier to use. It is also easy to add new features to the software by implementing them as a new widget and add them to the QStackedWidget and a navigation bar item to the QListWidget as a QListWidgetItem.

The biggest challenge of the project was performance but thanks to the header that the ADAS sends each frame it was easy to see if frames were missed or not by reading bit 28 and 29 which indicated how many frames were missed. The largest factor was how many samples that were plotted. In order to solve that problem a decimation of order 10 was implemented, before decimation the samples went through a moving average mean filter to prevent aliasing.

### 5.2 Ethical aspects of using the application

The produced software is not certified as a medical device and should therefore not be used for diagnosis or treatment purposes. Before using the software the user must know that the software is provided as is and that it is intended for scientific and educational purposes.

## 6 CONCLUSIONS

An application that can view an ECG in “real-time” and view an already recorded ECG while being limited by the processing power of the RPI has been developed and a description on how the application is working were shown in chapter 4.

Qt is a framework suitable for development of software where performance is of importance. It has the power of the C++ programming language along with features such as the signal & slot mechanism making multithreading easier to implement.

The RPI combined with the Biosignal Pi shield is small in size but still has the power to show an ECG in real-time which makes good start for future projects.

## 7 FUTURE WORK

### 7.1 Additional features

Additional features that could be added in future versions of the software could be HRV-calculations, Bluetooth communication and communication with a web server. Qt has modules for Bluetooth communication for Linux devices with Bluez 4.x installed. If Bluetooth support could be implemented, data could be sent to a smartphone or another computer easily. Qt also supports websockets which could be used to send data to a server.

### 7.2 Future work

It would be interesting to see if the software could run faster on a multicore device where the GUI thread and sampling thread run on different cores, this way true concurrency can be achieved. A multicore device similar to the RPI is the UDOO board which features a more powerful quad-core CPU along with an additional CPU dedicated to GPIO communication. [27]

## 8 EXPERIENCE GAINED

This project has been interesting in many ways and a lot of new experiences have been gained. Before this I had never used a Linux operating system before so setting up the cross compiling environment and installing Linux was something new to me.

Working with Qt and C++ was also something that I had never done before but it ended up working fine. The knowledge was mostly gained from studying sample code on the web and also by asking other developers when I got stuck or was wondering if there was a “best practice” to solve a specific task.

I think that the experience gained in this project will be useful in future projects as well, especially when it comes to software development. I’ve learned how hard it can be to determine how long it will take to implement a seemingly simple task.

## REFERENCES

[1] P. Zweifel, S. Felder and M. Meiers, “Ageing of population and health care expenditure: a red herring?”.
[2] G. B. Devey and W. A. Herman, “FUTURE TRENDS IN MEDICAL DEVICE TECHNOLOGIES: A Ten-Year Forecast,” 2011.
[3] Stockholms Läns Landsting, “Framtidsplanen andra steget – konkretisering av det fortsatta arbetet”.
[4] F. Abtahi, B. Aslamy, I. Boujabir, F. Seoane and K. Lindecrantz, “An Affordable ECG and Respiration Monitoring System based on Raspberry PI and ADAS1000 : First Step towards Homecare Applications,” in 16th Nordic-Baltic Conference on Biomedical Engineering & Medical Physics 2014, Stockholm, 2014.
[5] G. J. Tortora and B. H. Derrickson, The principles of anatomy and physiology, 13 ed., John Wiley Sons, 2011.
[6] M. Cadogan, “Lif In The Fast Lane,” [Online]. Available: http://lifeinthefastlane.com/education/procedures/lead-positioning/. [Accessed 19 7 2014].
[7] P. Pitigalaarachchi, “ECG simulation using MATLAB, a mathematical approach,” [Online]. Available: http://thepansilu.blogspot.se/2010/11/ecg-simulation-using-matlab.html. [Accessed 19 7 2014].
[8] Raspberry Pi Foundation, [Online]. Available: http://www.raspberrypi.org/. [Accessed 19 7 2014].
[9] Broadcom, BCM2835 ARM Peripherals, 2012.
[10] Byte Paradigm, “Introduction to I²C and SPI protocols,” [Online]. Available: http://www.byteparadigm.com/applications/introduction-to-i2c-and-spi-protocols/. [Accessed 23 7 2014].
[11] Analog Devices, “Analog Devices,” [Online]. Available: http://www.analog.com/en/analog-to-digital-converters/ad-converters/adas1000/products/product.html. [Accessed 22 7 2014].
[12] Analog Devices, Low Power, Five Electrode Electrocardiogram (ECG) Analog Front End, 2012.
[13] J. Blanchette and M. Summerfield, C++ GUI Programming with Qt 4, Prentice Hall, 2006.
[14] Qt Project, “Qt Licensing,” [Online]. Available: http://qt-project.org/products/licensing. [Accessed 27 7 2014].
[15] GNU, “GNU General Public License,” [Online]. Available: http://www.gnu.org/licenses/gpl.html. [Accessed 27 7 2014].
[16] GNU, “GNU Lesser General Public License, version 2.1,” [Online]. Available: http://www.gnu.org/licenses/old-licenses/lgpl-2.1.html. [Accessed 27 7 2014].
[17] Qt Project, “Qt Widgets,” [Online]. Available: https://qt-project.org/doc/qt-

5/qtwidgets-index.html. [Accessed 27 7 2014].
[18] Qt Project, “Signals & Slots,” [Online]. Available: http://qt-project.org/doc/qt-5/signalsandslots.html. [Accessed 27 7 2014].
[19] Qt Project, “Threading Basics,” [Online]. Available: http://qt-project.org/doc/qt-5/thread-basics.html. [Accessed 31 7 2014].
[20] Qt Project, “Synchronizing Threads,” [Online]. Available: http://qt-project.org/doc/qt-5/threads-synchronizing.html. [Accessed 31 7 2014].
[21] Qt Project, “Multithreading Technologies in Qt,” [Online]. Available: http://qt-project.org/doc/qt-5/threads-technologies.html. [Accessed 31 7 2014].
[22] M. Rouse, “Iterative development,” TechTarget, [Online]. Available: http://searchsoftwarequality.techtarget.com/definition/iterative-development. [Accessed 9 8 2014].
[23] A. Wiley, “Iterative Software Development Approach,” 11 6 2008. [Online]. Available: https://wiki.nci.nih.gov/x/eKZ8. [Accessed 9 8 2014].
[24] B. Kemp, “European Data Format,” [Online]. Available: http://www.edfplus.info/. [Accessed 11 8 2014].
[25] C. Becchetti and A. Neri, Medical instrument design and development : from market to placements, John Wiley & Sons Ltd., 2013.
[26] M. McCauley, “C library for Broadcom BCM 2835 as used in Raspberry Pi,” [Online]. Available: http://www.airspayce.com/mikem/bcm2835/. [Accessed 4 8 2014].
[27] udoo.org, “UDOO : Features,” SECO USA Inc, [Online]. Available: http://www.udoo.org/features/. [Accessed 13 8 2014].
[28] eLinux, “Embedded Linux Wiki,” [Online]. Available: http://elinux.org/Main_Page. [Accessed 23 7 2014].
[29] Qt Project, “Cross-Compiling Qt for Embedded Linux Applications,” [Online]. Available: http://qt-project.org/doc/qt-4.8/qt-embedded-crosscompiling.html. [Accessed 27 7 2014].

APPENDIX A: A comparison between the Raspberry Pi Model A and B

The RPI Model A to the left and Model B to the right.

Technical specifications
Chip | Broadcom BCM2835 SoC full HD multimedia applications processor | Broadcom BCM2835 SoC full HD multimedia applications processor
CPU | 700 MHz Low Power ARM1176JZ-F Applications Processor | 700 MHz Low Power ARM1176JZ-F Applications Processor
GPU | Dual Core VideoCore IV® Multimedia Co-Processor | Dual Core VideoCore IV® Multimedia Co-Processor
Memory | 256MB SDRAM | 512MB SDRAM
Ethernet | None | onboard 10/100 Ethernet RJ45 jack
USB 2.0 | Single USB Connector | Dual USB Connector
Video Output | HDMI (rev 1.3 & 1.4) Composite RCA (PAL and NTSC) | HDMI (rev 1.3 & 1.4) Composite RCA (PAL and NTSC)
Audio Output | 3.5mm jack, HDMI | 3.5mm jack, HDMI
Onboard Storage | SD, MMC, SDIO card slot | SD, MMC, SDIO card slot
Operating System | Linux | Linux
Dimensions | 8.6cm x 5.4cm x 1.5cm | 8.6cm x 5.4cm x 1.7cm

APPENDIX B: How to compile and install Qt, install qwt and overclock the RPI

How to cross-compile and install Qt

Go to the /home/<user>/ folder and create a new one:

/ $ mkdir opt
/ $ cd opt

Go to http://www.raspberrypi.org/downloads/ and download the latest image to the

/home/<user>/opt/ folder, unzip it:

/ $ unzip <date>-wheezy-raspbian.zip

Mount the file system of the raspbian image:

/ $ sudo mkdir ./mnt/rasp-pi-rootfs
/ $ sudo mount -o loop,offset=62914560 <date>-wheezy-raspbian.img /mnt/rasp-pi-rootfs

Download and extract the cross compile toolchain: (check the link in the beginning if this one doesn't work)

/ $ wget http://swap.tsmt.eu/gcc-4.7-linaro-rpi-gnueabihf.tbz/ $ tar -xf gcc-4.7-linaro-rpi-gnueabihf.tbz

Install the ia32libs if a 64 bit system is used:

/ $ sudo apt-get install ia32-libs

Clone cross compile-tools and Qt5 repository:

/ $ git clone
git://gitorious.org/cross-compile-tools/cross-compile-tools.git / $ git clone git://gitorious.org/qt/qt5.git

Init the repository:

/ $ cd qt5
/ $ ./init repository

Go back to opt:

/ $ cd ..

Go to the cross compile-tools directory and fix library paths:

/ $ cd cross-compile-tools
/ $ sudo ./fixQualifiedLibraryPaths /mnt/rasp-pi-rootfs/ ~/opt/gcc-4.7-linaro-rpi-gnueabihf/bin/arm-linux-gnueabihf-gcc

Go to the qtbase folder:

/ $ cd ..
/ $ cd qt5/qtbase

Then run:

/ $ ./configure -opengl es2 -device linux-rasp-pi-g++ -device-option
CROSS_COMPILE=~/opt/gcc-4.7-linaro-rpi-gnueabihf/bin/arm-linux-gnu
eabihf- -sysroot /mnt/rasp-pi-rootfs -opensource -confirm-license
-optimized-qmake -reduce-relocations -reduce-exports -release -make libs -prefix/usr/local/qt5pi
/ $ make -j 4
/ $ sudo make install

You now have qmake so you will be able to compile qt-applications. There are also other modules in the qt5 folder that can be installed. To compile and install other modules enter their folder, run your qmake, make and then make install.

Example:

/ $ cd <module>
/ $ /usr/local/bin/qmake . / $ make -j 4
/ $ sudo make install

Recommended modules: qtimageformats, qtsvg, qtjsbackend, qtscript, qtxmlpatterns, qtdeclarative, qtsensors, qt3d, qtgraphicaleffects, qtjsondb, qtlocation, qtdocgallery

When qtbase and additional modules are installed it is time to copy the image to the SD-card.

/ $ sync; sudo umount /mnt/rasp-pi-rootfs
/ $ sudo dd bs=1M if=<date>-wheezy-raspbian.img of=/dev/sdX; sync

How to install qwt

Qwt version 6.1.0 is required in order to compile the project. The Qwt library can be downloaded here: http://sourceforge.net/projects/qwt/files/qwt/6.1.0/qwt-6.1.0.tar.bz2/download

In order to install the Qwt library a functional qmake is required, make sure qt is working by compiling the example in the link in the beginning.

Make sure that the image is mounted!

/ $ cd /opt
/ $ sudo mount -o loop,offset=62914560 <date>-wheezy-raspbian.img /mnt/rasp-pi-rootfs

To install qwt, navigate to the folder where the unpacked tarball is located:

/ $ cd qwt-6.1.0
/ $ /usr/local/bin/qmake .
/ $ make -j 4

/ $ sudo make install

This should install qwt on your computer and on the mounted image, either overwrite your current image or transfer the installed library to the RPI.

To overwrite, insert the SD-card, check the entry point, then do:

/ $ sync; sudo umount /mnt/rasp-pi-rootfs
/ $ sudo dd bs=1M if=<date>-wheezy-raspbian.img of=/dev/sdX; sync

How to overclock the RPI

It is recommended to overclock the RPI for some extra performance, boot the pi and log in, then issue the following command:

/ $ sudo raspi-config

Navigate to option #7, overclock

Choose 800 MHz, it should be enough!

Ok → Finish

APPENDIX C: Images of the Biosignal Pi

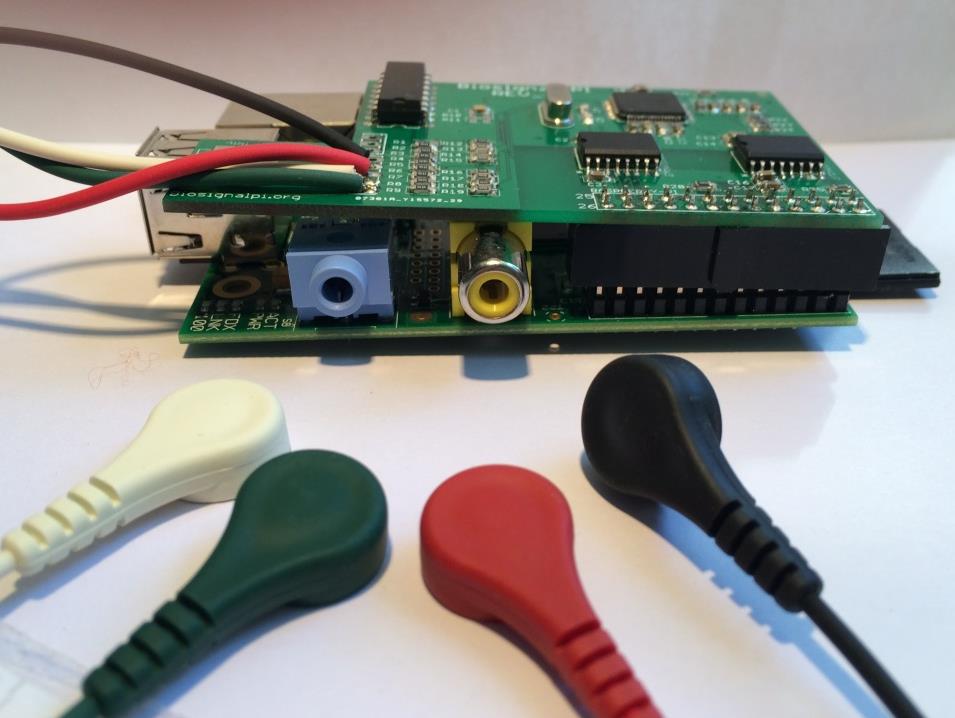
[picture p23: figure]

The Biosignal Pi shield mounted on top on a Raspberry Pi model B viewed from the side.

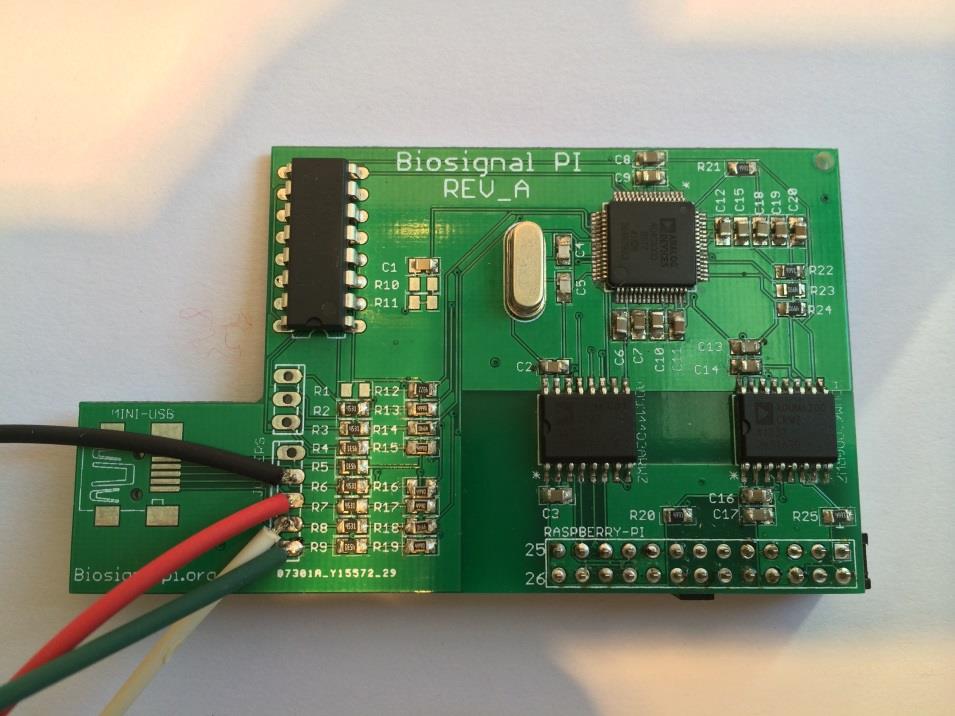
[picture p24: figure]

The Biosignal Pi shield viewed from the top.

Appendix D: User guide

Starting the application

In order to start the application, navigate to the folder it is placed in and issue the following command:

sudo ./BiosignalPI

The program should then load and the starting screen will appear. On the bottom of the screen there is a menu that the user can use to navigate through the different views of the program. There is also a button used to take a snapshot of the current screen, this can be useful if the user spots something interesting during ECG capture. There is also a quit button that will exit the application.

Note: excessive use of the snapshot button will decrease the system performance and may result in a frame drop during ECG capture.

How to record an ECG

When the program has started and before and ECG can be recorded the user should go to the settings view by clicking on “settings” in the menu at the bottom of the screen.

The user should first choose a source. If the user wants to record an ECG the “ECG” option should be selected. The user can also choose a number of different test tones in order to verify that the system is working correctly.

When the source is selected the user should choose a sampling rate, the 1 kHz option is selected by default and is the recommended option. The user can also choose the 2 kHz and 500 Hz option.

Note: frame drops have been observed when choosing the 2 kHz option.

When source and sample rate have been selected there are a number of additional fields that can be filled in. These are optional and it will still be possible to record an ECG without filling in the fields. If the user choose to leave the filename blank the filename will be “ECG” by default.

Note: if a filename has the same name as an already existing file, the old file will be overwritten.

When the settings are applied the user should click on “ECG capture” in the menu on the bottom of the screen.

If the user has chosen one of the test tone options in the settings the user could click on the “Start ECG capture” button without connecting the electrodes, which will start the data collection.

If the user chooses the ECG option in the settings menu it will have to attach the electrodes to the chest by placing one electrode on the upper part of the chest close to the right shoulder and one on the opposite side. One electrode should be placed on the lower right part of the belly and another electrode should be placed on the other side. When the electrodes are connected to the lead the user can press the “Start ECG capture” button. When the user is finished with the data collection the “Stop ECG capture” button should be pressed, this will stop the data collection and the data will be stored to a text-file and also as an EDF-file if the option is selected in the settings view.

How to view a recorded ECG

When an ECG has been recorded the user can view the recorded ECG by clicking on the “View ECG” button in the menu on the bottom part of the screen.

To get a list of recorded ECG files the “Get ECG files” button should be pressed, recorded ECGs are stored in two files, one data file and one header file. The user should double click on the file containing the ECG data. This will load the recorded ECG and its header.

Loaded ECG’s will by default have the 5s window size selected but the user can choose to the window size to be either 5 s, 10 s, 1 min or the whole recording. To navigate through the ECG the user can use either the mouse scroll button, the scrollbar below the plots or the navigation buttons on the left side of the scroll bar. The user can also choose to playback the ECG by clicking on the play button.

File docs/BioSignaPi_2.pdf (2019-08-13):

Sensors 2015, 15, 93-109; doi:10.3390/s150100093

# sensors

ISSN 1424-8220
www.mdpi.com/journal/sensors Article

## Biosignal PI, an Affordable Open-Source ECG and Respiration Measurement System

Farhad Abtahi ¹,*, Jonatan Snäll ¹

, Benjamin Aslamy ¹, Shirin Abtahi ¹, Fernando Seoane ¹,2 and Kaj Lindecrantz ¹,3

1
School of Technology and Health, Royal Institute of Technology, Alfred Nobels Allé 10, Stockholm SE-141 52, Sweden; E-Mails: jsnall@kth.se (J.S.); aslamy@kth.se (B.A.); shirin.abtahi@gmail.com (S.A.); fsm@kth.se (F.S.); kaj.lindecrantz@sth.kth.se (K.L.) 2 Academy of Care, Wellbeing and Welfare, University of Borås, Allégatan 1,
Borås SE-501 90, Sweden
3 Department of Clinical Science, Intervention and Technology, Karolinska Institutet, Hälsovägen 7, Stockholm SE-141 57, Sweden

* Author to whom correspondence should be addressed; E-Mail: farhad.abtahi@sth.kth.se; Tel.: +46-704-689-002.

Academic Editor: Panicos Kyriacou

Received: 30 October 2014 / Accepted: 15 December 2014 / Published: 23 December 2014

Abstract: Bioimedical pilot projects e.g., telemedicine, homecare, animal and human trials usually involve several physiological measurements. Technical development of these projects is time consuming and in particular costly. A versatile but affordable biosignal measurement platform can help to reduce time and risk while keeping the focus on the important goal and making an efficient use of resources. In this work, an affordable and open source platform for development of physiological signals is proposed. As a first step an 8–12 leads electrocardiogram (ECG) and respiration monitoring system is developed. Chips based on iCoupler technology have been used to achieve electrical isolation as required by IEC 60601 for patient safety. The result shows the potential of this platform as a base for prototyping compact, affordable, and medically safe measurement systems. Further work involves both hardware and software development to develop modules. These modules may require development of front-ends for other biosignals or just collect data wirelessly from different devices e.g., blood pressure, weight, bioimpedance spectrum, blood glucose, e.g., through Bluetooth. All design and development documents, files and source codes will be available for non-commercial use through project website, BiosignalPI.org.

OPEN ACCESS

Sensors 2015, 15 | 94

Keywords: affordable ECG; Raspberry PI; ADAS1000 analog front-end; open-source; respiration monitoring; thoracic bioimpedance; Medical device development

### 1. Introduction

An aging population—an increased percentage of elderly individuals in the overall population—is challenging the current healthcare system by increasing costs, creating a lack of healthcare personnel, and contributing to more complex combinations of chronic diseases [1]. In addition, the spreading of a western lifestyle—low physical activity, combined with a high calorie diet, rich in fat and sugar—has become associated with chronic diseases such as diabetes and cardiovascular diseases in industrialized countries [2,3]. This trend is now noticeable even in developing countries and hence demands for healthcare are expected to rise in the near future [4]. Improvement of healthcare and management of chronic diseases with new methods is the aim of many multidisciplinary researches. These researches include pre-clinical animal trials and clinical human trials of new screening, diagnosis, intervention and treatment methods. These projects typically involve physiological and biological measurements e.g., blood pressure, blood glucose, weight, body composition, activity monitoring, and electrical cardiac activity through electrocardiogram (ECG).
Telemedicine and homecare is a special case, utilising recent advances in information technology (IT). It is sometimes considered a potential solution for increasing patients’ quality of life by expanding the accessibility of healthcare and even optimal distribution of healthcare costs [4]. However, these ideas are neither fully proven nor discarded. One of the reasons is the diverse set of measurements and IT systems needed for each individual project. Different sensors and analogue front-ends are required for physiological monitoring of each target patient group, thus demanding application specific biomedical measurement and IT systems. Development of such diverse systems makes technical development of studies in homecare/telemedicine costly and, in particular, time consuming. Subsequently, less time and effort is remaining to engage healthcare personal and target patients.
A flexible platform for fast prototyping of systems in these scenarios can be very useful in pilot projects and for proof of concept. Another benefit of such flexible platforms is for education purposes in the field of biomedical engineering, allowing students to get familiarized with the whole chain of acquisition, processing and presentation of biological signals through a hands-on approach early on the educational program. The best example of such an educational platform is Gamma Cardio (openECG) [5], this open licence project along with a textbook [6] can be used by students to explore the process of medical devices developments. There are other open source projects like OpenMind [7], OpenEEG [8] and OpenBCI [9] which can provide enormous learning resources. However, all of these projects have a limited number of channels and in particular are designed for specific biosignals like EEG with minimum flexibility for covering more measurements. In addition, they are not standalone device and to be functional need a PC, laptop or mobile phone for visualization and analysis of signals which make the whole solution more costly.
The intention of this work is to design an open-source, flexible and affordable framework for developing safe biosignal measurement devices. This framework, we call it Biosignal PI, can be used by researchers, students, and engineers, or even hobbyists, without a deep knowledge of embedded systems, measurement technology or biomedical instrumentation. This framework is modular and electrically safe, and it fulfils many medical standards. ECG has been widely applied for diagnosis and monitoring heart disease, in monitoring the autonomic nervous system through heart-rate variability (HRV) and also for various sports-training applications. Therefore an ECG and respiration measurement module developed as a first example for developing and evaluating the design [10]. This prototype is developed further as Biosignal PI project.

### 2. Constrains

Flexibility is a key feature of a biosignal measurement prototyping framework. It should be scalable for different demands in different projects while still providing high reliability. Each biosignal has specific requirements such as sampling rate, frequency range, specific amplification and safety constrains as specified by relevant medical standards.

### 3. System Design

3.1. Embedded Platform

During the last decade, development of microelectronics has provided smaller, faster and more affordable computational platforms. Since flexibility is the main constrain for Biosignal PI, the chosen embedded platform should provide possibility for modular development of hardware and software. Modular hardware development can be done with microcontroller based systems as is done in Arduino projects [11]. However, systems based on operating systems like Linux can provide higher degree of flexibility and hence are more favourable for this kind of development compare to firmware development for microcontrollers. Several compact single-board computers are introduced and have got popular in the last five years e.g. Raspberry PI (RPI) and BeagleBone Black. RPI [12]—a credit-card-size single-board computer with an ARM processor—was chosen for this project, see Figure 1. The RPI is developed by Raspberry Foundation. The main reasons for choosing RPI over its competitors were the affordable price and the active open-source community with enormous amount of projects, shields, and tutorials.


Figure 1. The Raspberry PI Model B (source: Raspberry PI website).

RPI comes in three models; A, B and recently B+. All models use the same CPU and GPU, the difference is in the RAM size and ports. It was initially designed to be an affordable compact computer, supporting students in studies in computer science. However, the presence of a general purpose input/output port (GPIO) made it a popular platform for development of many embedded projects. Model B, the type used in this project, provides an Ethernet port, two USB and one HDMI ports, audio and video outputs; and it has a 700 MHz CPU, GPU, 512 MB RAM and SD card slot. RPI supports several Linux distributions e.g., Raspbian; Debian based distribution optimized for the Raspberry PI hardware. Since it runs on Linux operating system, the programming language is not limited in anyway but Python, C/C++ and Java are among the more popular in the RPI community. Recently, RPI is also supported by Simulink which opens for new ways of learning embedded programming concepts without coding [13]. It is easy to set up a light web server e.g., Lighttpd and Apache, a database server e.g., SQLite, MySQL for specific applications.

3.2. Electrocardiogram and Thoracic Bioimpedance Analog Front-End

As mentioned before, an ECG and respiration monitoring system is chosen as the first example in the development of Biosignal PI. Respiration can be recorded via measurement of bioimpedance, i.e., by injecting a small current across the thorax and then sense the corresponding voltage drop. During inhalation, thorax expands, and as air fills the lungs the bioimpedance increases as the conductive surface for the current increases. During exhalation the bioimpedance decreases again [14]. Acquisition of ECG and thoracic bioimpedance can be done through several approaches, from the use of only discrete electronic components to totally integrated analogue front-ends. Integrated front-ends not only reduce the size and power consumption, it also provide a wide range of extra features like lead-off detection and compliance to medical standards such as AAMI EC11, AAMI EC38, IEC 60601-1, IEC 60601-2-25, IEC 60601-2-27 and IEC 60601-2-51. The main competitors for ECG front-ends are the ADAS1000-X from Analog Devices [15] and the ADS129X from Texas Instruments [16]. Both series have almost comparable specifications. ADS1298 can provide eight channels of ECG signals in one chip, good for development of a more compact and slightly cheaper 12-lead ECG device, compared to ADA1000 that has maximum five channels. Nonetheless ADAS1000 (ADAS) was chosen in this work, mainly because ADS1298R is only available in a NFBGA package. For prototyping manual mounting can be crucial and the LQFP package of ADAS is much easier to handle than NFBGA packaging.
The ADAS can provide a sample rate of up to 128 kHz and is suitable for portable battery-operated devices, bedside patient monitoring, portable telemetry, and home monitoring systems. ADAS chips can be used in gang mode to provide more ECG channels [15]. In this work, one/two ADAS1000BSTZ is used—that is, the five-channel version that includes all features—as a master and optional slave to provide 8-12 leads ECG in version A and B, respectively. Alternatively, a more affordable version ADAS1000-2BSTZ can be used as slave chip. The chip is used with LQFP 64 pin package, see Figure 2. It is worth to mention that manual soldering of LQFP64 package is relatively difficult and needs some experience and high level of soldering skills.
Typically, a 12-leads ECG uses nine electrodes and right-leg drive (RLD). Three electrodes connected to limbs; right arm (RA), left arm (LA) and left leg (LL) and the remaining six electrodes, named V1-V6, and are positioned on well-defined locations on the chest. Table 1 summarises the composition of the typical 12-leads ECG system. The calculation of aVR, aVL and aVF leads are not done by ADAS, they will have to be calculated as part of the subsequent processing. The V1 and V2 channels can be configured to work as either ECG input or as auxiliary input to perform other measurements.


Figure 2. The ADAS1000BSTZ with LQFP64 package is depicted on the right and the one placed on the LQFP adapter (used in a first prototype with in-house manufactured PCB) is on the left.

Table 1. Leads name and composition of ECG leads by using one or two ADAS [15].

ADAS | Lead Name | Composition

Master

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
LA – RA
LL – RA
LL – LA
RA – 0.5 × (LA + LL)
LA – 0.5 × (LL + RA)
LL – 0.5 × (LA + RA)
V1 – 0.333 × (LA + RA + LL) V2 – 0.333 × (LA + RA + LL)

Slave

V3
V4
V5
V6

V3 – 0.333 × (LA + RA + LL) V4 – 0.333 × (LA + RA + LL) V5 – 0.333 × (LA + RA + LL) V6 – 0.333 × (LA + RA + LL)

Note: aVR, aVL and aVF are not provided by ADAS and should drive by calculation.

Respiration measurements are done through thoracic bioimpedance measurements at a programmable frequency from 46.5 kHz to 64 kHz. Respiration measurement can be done on one of the limb leads (Lead I, II or III) or through separate leads connected a pair of dedicated pins [15]. Extended information about principles and applications of bioimpedance measurements is available in [17].
ADAS provides lead-off detection by injecting a DC or an AC current, to monitor the changes in the voltage to detect if an electrode is no longer connected to the patient. The detection has a delay which is below 10 ms for the AC mode, in the DC mode the delay depends on the programmed current and the cable capacitance.

3.3. Communication between RPI and ADAS

Communication between analogue front-ends, other integrated circuits, and RPI can be done through different ports e.g., serial peripheral interface (SPI), inter-integrated circuit (I²C) and universal asynchronous receiver/transmitter (UART). ADAS uses SPI which requires four links to communicate between one master and several slaves, a clock signal (SCLK) for synchronization, a slave select signal (SSn) and two data lines: master-out-slave-in (MOSI) and master-in-slave-out (MISO). Communication is controlled by the master, which selects the slave, activates the clock, and generates information on MOSI while it samples the MISO [18]. In this prototype, RPI acts as the master, communicating with one/two ADAS as slave.

3.4. Defibrillator and ESD Protection

In applications with risk of defibrillation e.g., in intensive or in emergency care protection against overvoltage is required. In other fields of application it is still recommended, as it may protect the device from other types of electrostatic discharge (ESD). The ESD protection layer is designed according to the recommendations in the ADAS datasheet [15]. The protection circuit is based on SP720, which provides protection up to 8 kV against ESD and other transient overvoltage events [19].

3.5. Electrical Safety Insulation Layer

Electrical safety is among the most important requirements in medical device design. International Electrotechnical Commission (IEC) standards cover two types of insulation for user protection, IEC 60601 and IEC 60950. To prevent cause electric shock, cardiac arrhythmias, burns, or even damage to internal organs [20], the user (patient/operator) should be isolated from the high-voltage parts of the system, and the leakage currents must be kept low.
Isolation can be implemented at different levels. For applications with no connection, direct or indirect, to the power-line voltage e.g., battery-driven Holter devices the problem is automatically solve. However, as there may be a need for connecting RPI to peripherals e.g., printer, monitor, LAN, a proper isolation is included into the design. Isolation is achieved by insulating both the data (SPI) and DC power links between ADAS and RPI, as illustrated in Figure 3.
Optocouplers are typical components use to achieve insulation, signals are transferred between isolated parts and none isolated part using light. An alternative is iCoupler technology, combining high-speed CMOS and monolithic air core transformer technology, which allows lower cost, size, power, and higher reliability compared to optocouplers [21]. The SPI and DC lines are isolated by using the ADuM64XX and ADuM44XX family from Analog Devices. They provide 5 kV isolation, thus comply with IEC 60601 and IEC 60950. The ADuM6200 provides isolated DC power, and ADuM4400 gives isolated digital communication, allowing a bit rate of 90 Mbps [22–24].


Figure 3. System Architecture: Analog front-end, Raspberry PI (RPI), defibrillation protection, and patient isolation and RPI peripherals. Signals collect and process by RPI, and results can be shown on a monitor or printer or be saved on an SD card; data can even sent/received by Bluetooth, Wi-Fi or ZigBee to/from another device or cloud service.

3.6. Software Development

As discussed before, RPI provides plenty of freedom of choice regarding operating system and programming language. In this work Raspbian Linux and C++ were chosen for implementation of software that initializes the ADAS, retrieves the signals from it, and visualizes and records the signals in a desired format. For the graphical user interface (GUI) development Qt, a cross-platform application framework using standard C++, is used. The Qt also facilitates multi-threading. The Qt is a very popular framework with excellent documentation and useful examples [24]. As compiling an application on the RPI could slow down development process, cross compilation on a PC with Ubuntu OS [18] is used to produce executable code for the RPI platform. In order to achieve the required sampling rates above 2 kHz while the signals are plotted, sampling is done in an independent thread from GUI. Communication between these two threads is done by a method from Qt called signal & slot. This mechanism uses a queued connection which means that the signal is placed in the GUI threads event loop and the GUI is allowed to finish its current task before the slot is invoked [25].
Development of software for medical devices is regulated by several standards, such as ISO 13485, EN ISO 14971 and IEC 62304. These standards cover quality management systems, risk management and software lifecycle processes of medical devices, respectively [26]. Since the software development of this project does not meet any of these standards, it should be considered as software of unknown pedigree (SOUP). Any clinical use should be done after ensuring safe and reliable performance of the device. All responsibilities for this lay on the user, the authors of this paper assume no liabilities for the use of this material.
3.7. Biosignal PI Architecture

Figure 3 shows the proposed system architecture for Biosignal PI. The system includes RPI as a computational module, a digital and DC power isolation layer, electrostatic discharge (ESD) protection for body electrodes connected to analogue biosignal front-ends. Different biosignals and vital sign monitoring modules can be added by proper front-ends or as wireless monitors through Bluetooth, WiFi, or ZigBee. RPI may be connected to different peripherals such as monitor, printer and keyboard and even available shields for RPI depend on each demands of each project. RPI and potential peripherals are not designed as medical device and hence insulation layer is used to isolate the breakout board from RPI. Even if insulation and ESD protection characteristics are chosen to comply with requirements for patient safety, no steps towards formal certification have been taken. It is up to anyone who wants to base an MDD or FDA approved device on the Biosignal PI to make sure that all requirements are met.
In the first implementation of this architecture, ECG and respiration breakout board was designed for the ADAS1000 chip. The schematic and double-layer printed circuit board (PCB) was designed using the free version of CadSoft Eagle V6.5 [27]. Figure 4 shows the schematic diagram of a 5–8 leads system with all necessary components for operation of ADAS, ESD protection and isolation of board from RPI.

### 4. Results

The breakout board was designed in two versions, A and B, providing 5–8 or 12 leads ECG systems, respectively. The final dimensions of the PCB are 60 × 50 × 1.5 mm and 60 × 57 × 1.5 mm for versions A and B, respectively. Version B uses two ADAS chips to provide 12 leads and it also hosts a standard Db15 connector for the ECG cable. The assembled board of version A and its layout is shown in Figure 5; this is a 5–8 leads ECG and respiration version using one ADAS. Table 2 summarizes the main components used in the design and their approximate costs. The total cost exclude RPI is around $60 for the version A and $95 for the version B.
The implemented software can capture ECG and respiration signals at selectable sampling frequencies and visualize them in the real-time. The captured signals can be saved as text file or in European Data Format (EDF) [28]. The software currently provides an interface for browsing the recorded files. A screenshot of the Graphical User Interface (GUI) for browsing the recorded file is depicted in Figure 6. The screenshot illustrates a 10 s epoch of a 3-leads ECG and respiration for a healthy subject. The respiration activity is recorded by using thoracic impedance at 56 kHz through Lead I (right and left arms).


(a)
Figure 4. Cont.


(b)

(c)

Figure 4. Cont.


(d)

Figure 4. Schematic diagrams of prototype. GPIO Connector of Raspberry PI (a), Insulation layer for DC and SPI Communication using ADuM chips (b), ESD protection of ECG/external respiratory path by using SP720 (c) and ADAS1000 (d).

Table 2. Components cost.

Component | Cost ($) a | Cost ($) b
ADAS1000BSTZ | 35 | 22.5
ADAS1000-2BSTZ c | 20 | 13.5
ADuM4400 | 7.5 | 4
ADuM6403 | 13 | 8
SP720, 4kV diode array | 3.1 | 1.55
PCB Manufacturing | 5.4 | 3.45
Resistors, crystal, capacitors, connectors
and etc. | 10 | 6
Total Cost | 94 | 58

a

Cost for low volumes; b

Cost for batch of 1000; c
Optional as slave for 12-leads (Version B).


Figure 5. The prototype of Version A; PCB Layout with specified functional blocks (to the right) and assembled PCB (to the left). 4mm air clearance for creepage currents required by IEC 60601 can be recognized by black hachures in the layout and correspondent dark green area (area without copper) in the assembled PCB.

Figure 6. Screenshot of a recorded 3-leads ECG file.

### 5. Discussion

5.1. Cost

The total cost of the single prototype breakout board was around $76 for the 5-leads version; higher volumes will yield lower costs. The cost of the final standalone platform i.e., RPI and breakout board is affordable compare to solutions based on PCs and even tablets. In addition, adding other physiological measurements like blood pressure, body weight, and body composition will make the solution more versatile and also economical for homecare and telemedicine. RPI has given us a flexible platform for further development. It is possible to add Bluetooth, Wi-Fi, GSM/3G, printers, cameras, etc. simply by using a USB port or GPIO. It is worth mentioning that more USB ports can be added through a USB hub.

5.2. Thoracic Impedance Measurements and ADAS1000

The thoracic bioimpedance measurement for monitoring can be done through any of Lead I, Lead II, or Lead III. However, as Lead I measures across both lungs; lead I is the most suitable one for monitoring of respiration. As an alternative, it is possible to use separate electrodes for EBI measurements; these can be placed to optimize respiratory component in impedance signal. ADAS normally uses a two electrode configurations for EBI measurements (using the same pair of electrodes to inject the current and to measure the voltage); this method is sensitive to the skin-electrode impedance of electrodes, and it is not ideal for EBI measurements. Tetra-polar EBI measurement is a robust method that reduces the influence of electrode impedance and skin-electrode contact impedance by using one pair of electrodes for current injection and another pair for voltage measurement. It is possible to configure the ECG independent impedance measurement of ADAS to form a tetra-polar bioimpedance measurement system. This may potentially make ADAS a useful tool for impedance cardiography recording.

5.3. Raspberry PI as a Development Platform

In general, RPI can be used as a platform in an affordable homecare setting. Bluetooth, WIFI, GSM/3G/LTE and ZigBee can be used simply by employing USB dongles. Best of all, the RPI is available at a price of less than $60; RPI, including enclosure, power supply, and high-speed SD card. RPI Model B and B+ are fairly compact; however they are not suitable for specific projects like wearable devices.


Figure 7. The RPI Compute Model; 67.6 × 30 mm board as DDR2 SODIMM (Source: Raspberry PI website).

A recently introduced version, called Compute Module is aim to overcome this limitations. This module includes an RPi (the BCM2835 processor and 512 MB of RAM), 4 GB eMMC Flash and is integrated on to a small 67.6 × 30 mm board which fits into a standard DDR2 SODIMM connector. RPI Compute Module is depicted in Figure 7.
RPI is now facing a lot of competition, e.g., BeagleBone Black, Goosberry, UDOO, DragonBoard and Hackberry. These competitors usually provide better performance in terms of faster processors, bigger memory size, and more GPIO pins. The developed hardware is compatible with these platforms, and just need an adapter for connecting GPIO pins to correspondent pins of Biosignal PI. Since we have used the Qt development framework, porting the developed software to a new platform could be possible. The most important needed modification is GPIO communication module which is now based on Broadcom BCM2835 and should be modified according to the target platform.
5.4. Standard Compliances

As mentioned before, medical device functionality and safety of an ECG device is covered by several standards. The use of ADAS for the design gives free compliance to requirements for diagnostic ECG device. Table 3 summarizes the relevant standards and how they are covered in this design. Some of standards like EN 1041, EN 980 and EN 1041 are more related to manufacturing and support of a commercial device which is not covered by this project yet. This is not meant to be a full description of medical standards; more information can be found on relevant references like [6].

Table 3. Related standards and compliance of current version.

Standard | Topic | Covered by
AAMI EC 11 | Diagnostic electrocardiographic devices
| requirements | ADAS
EC 13 | Minimum safety and performance requirements
| for electrocardiograph (ECG) heart rate and
| waveform monitors | ADAS

EC 38

Particular requirements for the safety, including essential performance, of ambulatory electrocardiographic systems

ADAS

EN 1041 | Information from supplier | ------
EN 980 | Device Labelling | ------
IEC 61000 | Immunity to ESD and end electrical burst | SP720 Creepage air clearance
IEC/EN 6061-1-1 | General requirements of safety | ADAS ADUM
IEC/EN 6061-1-2 | Electromagnetic compatibility requirements and test

-Ground Planes
-Component
Segregation
-Decoupling
Capacitors
-Separation of traces

Table 3. Cont.

Standard | Topic | Covered by
IEC/EN 6061-2-25 | ECG Safety requirements | ADAS
IEC/EN 6061-2-27 | Particular requirements for the basic safety and essential performance of electrocardiographic monitoring equipment | ADAS

IEC/EN 6061-2-51

Particular requirements for safety, including essential performance, of recording and analysing single channel and multichannel electrocardiographs

ADAS

ISO/EN 10993-1 | Biological Evaluation | ------
ISO/EN 14971 | Risk Management | ------
ISO 13485 | Quality Management System | ------
ISO 62304 | Software lifecycle processes of medical devices | ------
5.5. Potential to Develop as a Wearable System

The proposed Biosignal PI system is relatively compact as a standalone device, but there is a trend towards even more compact and wearable devices for physiological measurements and wireless links to present data on mobile phones and smart watches. These products are usually not designed to act as main diagnostic tool by providing healthcare grade applications, they often intended for fitness and sport. For such wearable solutions, which in nature need more compact and different form factor than RPI Model B/B +, RPI Compute Module can be used. Further development can miniaturize the system in a way that it can be a part of personalized wearable health-monitoring solutions. Advances in textile electronics and printed electronics have demonstrated good performances for dry textile-based electrodes and printed electronics [29,30]. The ultimate solution might be a wearable system, such as the sensorized garments in the ATREC project [31] and the Textrode straps for impedance cardiography [32].

5.6. Laboratory Work, Design-Building Experiences and Learning Tool

The Raspberry PI foundation has provided an educational platform for kids. In addition, open-source projects and shields are developed by RPI community for home automation, robotics, etc. Further development of Biosignal PI can provide an educational platform for engineering students. Biomedical engineering is a multidisciplinary discipline integrating know-how from different fields and is likely that not all the students master embedded systems with enough proficiency to build the embedded system equivalent to RPI from scratch to implement a specific biomedical application. Biosignal PI together with some laboratory exercises could facilitate the implementation of teaching-learning activities focused on the acquisition and analysis of physiological signals [33]. This could be of particular interest in programs implementing the CDIO concept (Conceive-Design-Innovate and Operate) with a significant load of student centred learning specifically through Design-Build experiences [34].

5.7. Potential Future Development

The implemented software functions have demonstrated the features of lead-off detection, signal acquisition, storage as text or EDF file, illustration, and signal processing of the platform. Further software development will provide more controls over ADAS’s registers and processing options, such as heart-rate variability analysis. Transmission of signals over Bluetooth will also implement and uses as link with Bluetooth enabled devices such as some pulse oximeters, blood pressure devices, and weight scales. To explore educational potential of RPI for education of biomedical engineering, alongside with hardware/software developments; syllables and instructions for laboratory exercises and assignments of such courses is needed.

### 6. Conclusions/Outlook

An ECG and respiration measurement device has been developed as first step of Biosignal PI, a flexible compact platform for biosignal measurements. Further development of this platform will provide a flexible framework for fast prototyping and proof of concept in animal and human clinical studies or as a part of a personalized health-monitoring and homecare systems. It could also be developed as an affordable and versatile educational platform, in a similar manner that Arduino has contributed to facilitate learning of programming and embedded systems in the field of electronics [35–38].

Author Contributions

F.A. was the initiative and project manager of the work. Technical development was supervised by F.A. and K.L.; B.A. and S.A. have designed and implemented the hardware. B.A. evaluated the system by developing simple software. J.S. developed the final software. F.A. and S.A. wrote the initial manuscript; K.L. and F.S. participated actively in the development, revision and proofreading of the final manuscript.

Conflicts of Interest

The authors declare no conflict of interest.

References

1. Zweifel, P.; Felder, S.; Meiers, M. Ageing of population and health care expenditure: A red herring? Health Econ. 1999, 8, 485–496.
2. Hu, F.B. Globalization of diabetes the role of diet, lifestyle, and genes. Diabetes Care 2011, 34, 1249–1257.
3. Vorster, H. The emergence of cardiovascular disease during urbanisation of africans. Public Health Nutr. 2002, 5, 239–243.
4. Koch, S. Home telehealth—Current state and future trends. Int. J. Med. Inform. 2006, 75, 565–576.
5. Becchetti, C.; Neri, A. Gamma Cardio Cg. Available online: http://www.gammacardiosoft.it/openecg/#textbook (accessed on 8 July 2014).
6. Becchetti, C.; Neri, A. Medical Instrument Design and Development: From Requirements to Market Placements; John Wiley & Sons: Chichester, UK, 2013.

7. An Open Source Brain-Computer-Interface Hardware Design. Available online: https://github.com/jaseg/openmind (accessed on 8 July 2014).
8. Openeeg Project. Available online: http://openeeg.sourceforge.net/doc/ (accessed on 8 December 2014).
9. Openbci. Available online: http://openbci.com/ (accessed on 8 December 2014).
10. Abtahi, F.; Aslamy, B.; Boujabir, I.; Seoane, F.; Lindecrantz, K. In an affordable ECG and respiration monitoring system based on raspberry PI and ADAS1000: First step towards homecare applications. In Proceedings of the 16th Nordic-Baltic Conference on Biomedical Engineering, Gothenburg, Sweden, 14–16 October 2014; pp. 5–8.
11. Mellis, D.; Banzi, M.; Cuartielles, D.; Igoe, T. Arduino: An Open Electronic Prototyping Platform; Proc. CHI: San Jose, CA, USA, 2007.
12. Pi, R. An Arm GNU/LINUX Box for $25. Available online: http://www.raspberrypi.org/(accessed on 18 December 2014).
13. Kurniawan, A. Getting Started with Matlab Simulink and Raspberry PI; PE Press: Berlin, Germany, 2013.
14. Brown, B.H.; Smallwood, R.; Barber, D.; Lawford, P.; Hose, D. Medical Physics and Biomedical Engineering; CRC Press: New York, NY, USA, 1998.
15. Adas1000 Low Power, Five Electrode Electrocardiogram (ECG) Analog Front End. Available online: http://www.analog.com/static/imported-files/data_sheets/ADAS1000_1000-1_1000-2.pdf (accessed on 10 February 2014).
16. Instruments, T. Low-Power, 8-Channel, 24-Bit Analog Front-End for Biopotential Measurements. Available online: http://www.ti.com/lit/ds/symlink/ads1296.pdf (accessed on 18 December 2014).
17. Grimnes, S.; Martinsen, Ø.G. Bioimpedance & Bioelectricity Basics; Academic Press: Oxford, UK, 2000.
18. Leens, F. An introduction to I²
C and SPI protocols. Instrum. Meas. Mag. IEEE 2009, 12, 8–13.
19. Sp724 Series 3pf 8kv Diode Array Rohs Datasheet. Available online: http://www.littelfuse.com/~/media/electronics/datasheets/tvs_diode_arrays/littelfuse_tvs_diode_array_sp724_datasheet.pdf.pdf (accessed on 13 February 2014).
20. Krakauer, | D. | Isolating | the | USB | in | Medical | Systems. | Available | online:
http://www.devicelink.com/mem/archive/09/10/003.html (accessed on 13 February 2014).
21. Chen, B. Icoupler® Products with Isopower™ Technology: Signal and Power Transfer across Isolation Barrier using Microtransformers. Available online: http://www.analog.com/static/imported-files/overviews/isoPower.pdf (accessed on 18 December 2014).
22. Adum4400 5 kV RMS Quad-Channel Digital Isolators. Available online: http://www.analog.com/static/imported-files/data_sheets/ADuM4400_4401_4402.pdf (accessed on 10 February 2014).
23. Adum6400 Quad-Channel, 5 kv Isolators with Integrated DC-to-DC Converter. http://www.analog.com/static/imported-files/data_sheets/ADuM6400_6401_6402_6403_6404.pdf (accessed on 10 February 2014).
24. Blanchette, J.; Summerfield, M. C++ Gui Programming with Qt 4; Prentice Hall Professional: Westford, MA, USA, 2006.
25. Signals & Slots. Available online: http://qt-project.org/doc/qt-4.8/signalsandslots.html (accessed on 18 December 2014).

26. McHugh, M.; McCaffery, F.; MacMahon, S.T.; Finnegan, A. Improving safety in medical devices from concept to retirement. In Handbook of Medical and Healthcare Technologies; Springer: New York, NY, USA, 2013; pp. 453–480.
27. CadSoft EAGLE PCB Design Software. Available online: http://www.cadsoftusa.com/ (accessed on 18 December 2014).
28. Kemp, B.; Olivan, J. European data format ‘plus’ (EDF+), an EDF alike standard format for the exchange of physiological data. Clin. Neurophysiol. 2003, 114, 1755–1761.
29. Marquez, J.C.; Seoane, F.; Valimaki, E.; Lindecrantz, K. Textile electrodes in electrical bioimpedance measurements—A comparison with conventional AG/AGCL electrodes. In Proceedings of the Annual International Conference of the Engineering in Medicine and Biology Society, Minneapolis, MN, USA, 3–6 September 2009; pp. 4816–4819.
30. Xie, L.; Yang, G.; Xu, L.; Seoane, F.; Chen, Q.; Zheng, L. Characterization of dry biopotential electrodes. In Proceedings of the 35th Annual International Conference of the Engineering in Medicine and Biology Society (EMBC), Osaka, Japan, 3–7 July 2013; pp. 1478–1481.
31. Seoane, F.; Ferreira, J.; Alvarez, L.; Buendia, R.; Ayllón, D.; Llerena, C.; Gil-Pita, R. Sensorized garments and textrode-enabled measurement instrumentation for ambulatory assessment of the autonomic nervous system response in the atrec project. Sensors 2013, 13, 8997–9015.
32. Ruiz, J.C.M.; Rempfler, M.; Seoane, F.; Lindecrantz, K. Textrode-enabled transthoracic electrical bioimpedance measurements-towards wearable applications of impedance cardiography. J. Electr. Bioimpedance 2013, 4, 45–50.
33. Seoane, F.; Garrote Jurado, R.G.; Christie, M. Design-Build Experience-Based Program in Biomedical Engineering as a Practical Example of Science for Professions. Available online: http://library.iated.org/view/SEOANEMARTINEZ2010DES (accessed on 18 December 2014).
34. Salerud, E.G.; Ilias, M.A.; Häggblad, E. Design-build experiences and student-centered-learning in biomedical engineering curricula. In Proceedings of the 2nd International CDIO Conference, Linköping, Sweden, 13–14 June 2006.
35. Jamieson, P. Arduino for Teaching Embedded Systems. Are Computer Scientists and Engineering Educators Missing the Boat? Available online: http://www.users.miamioh.edu/jamiespa/html_papers/fecs_11.pdf (accessed on 18 December 2014).
36. Wilcher, D. Learn electronics with arduino; Springer: New York, NY, USA, 2012.
37. Buechley, L.; Eisenberg, M.; Catchen, J.; Crockett, A. In the lilypad arduino: Using computational textiles to investigate engagement, aesthetics, and diversity in computer science education. In Proceedings of the SIGCHI conference on Human factors in computing systems, Florence, Italy, 5–10 April 2008; pp. 423–432.
38. Irigoyen, E.; Larzabal, E.; Priego, R. Low-cost platforms used in control education: An educational case study. In Proceedings of the 10th IFAC Symposium in Control Education, Sheffield, UK, 28–30 August 2013; pp. 256–261.

© 2014 by the authors; licensee MDPI, Basel, Switzerland. This article is an open access article distributed under the terms and conditions of the Creative Commons Attribution license (http://creativecommons.org/licenses/by/4.0/).

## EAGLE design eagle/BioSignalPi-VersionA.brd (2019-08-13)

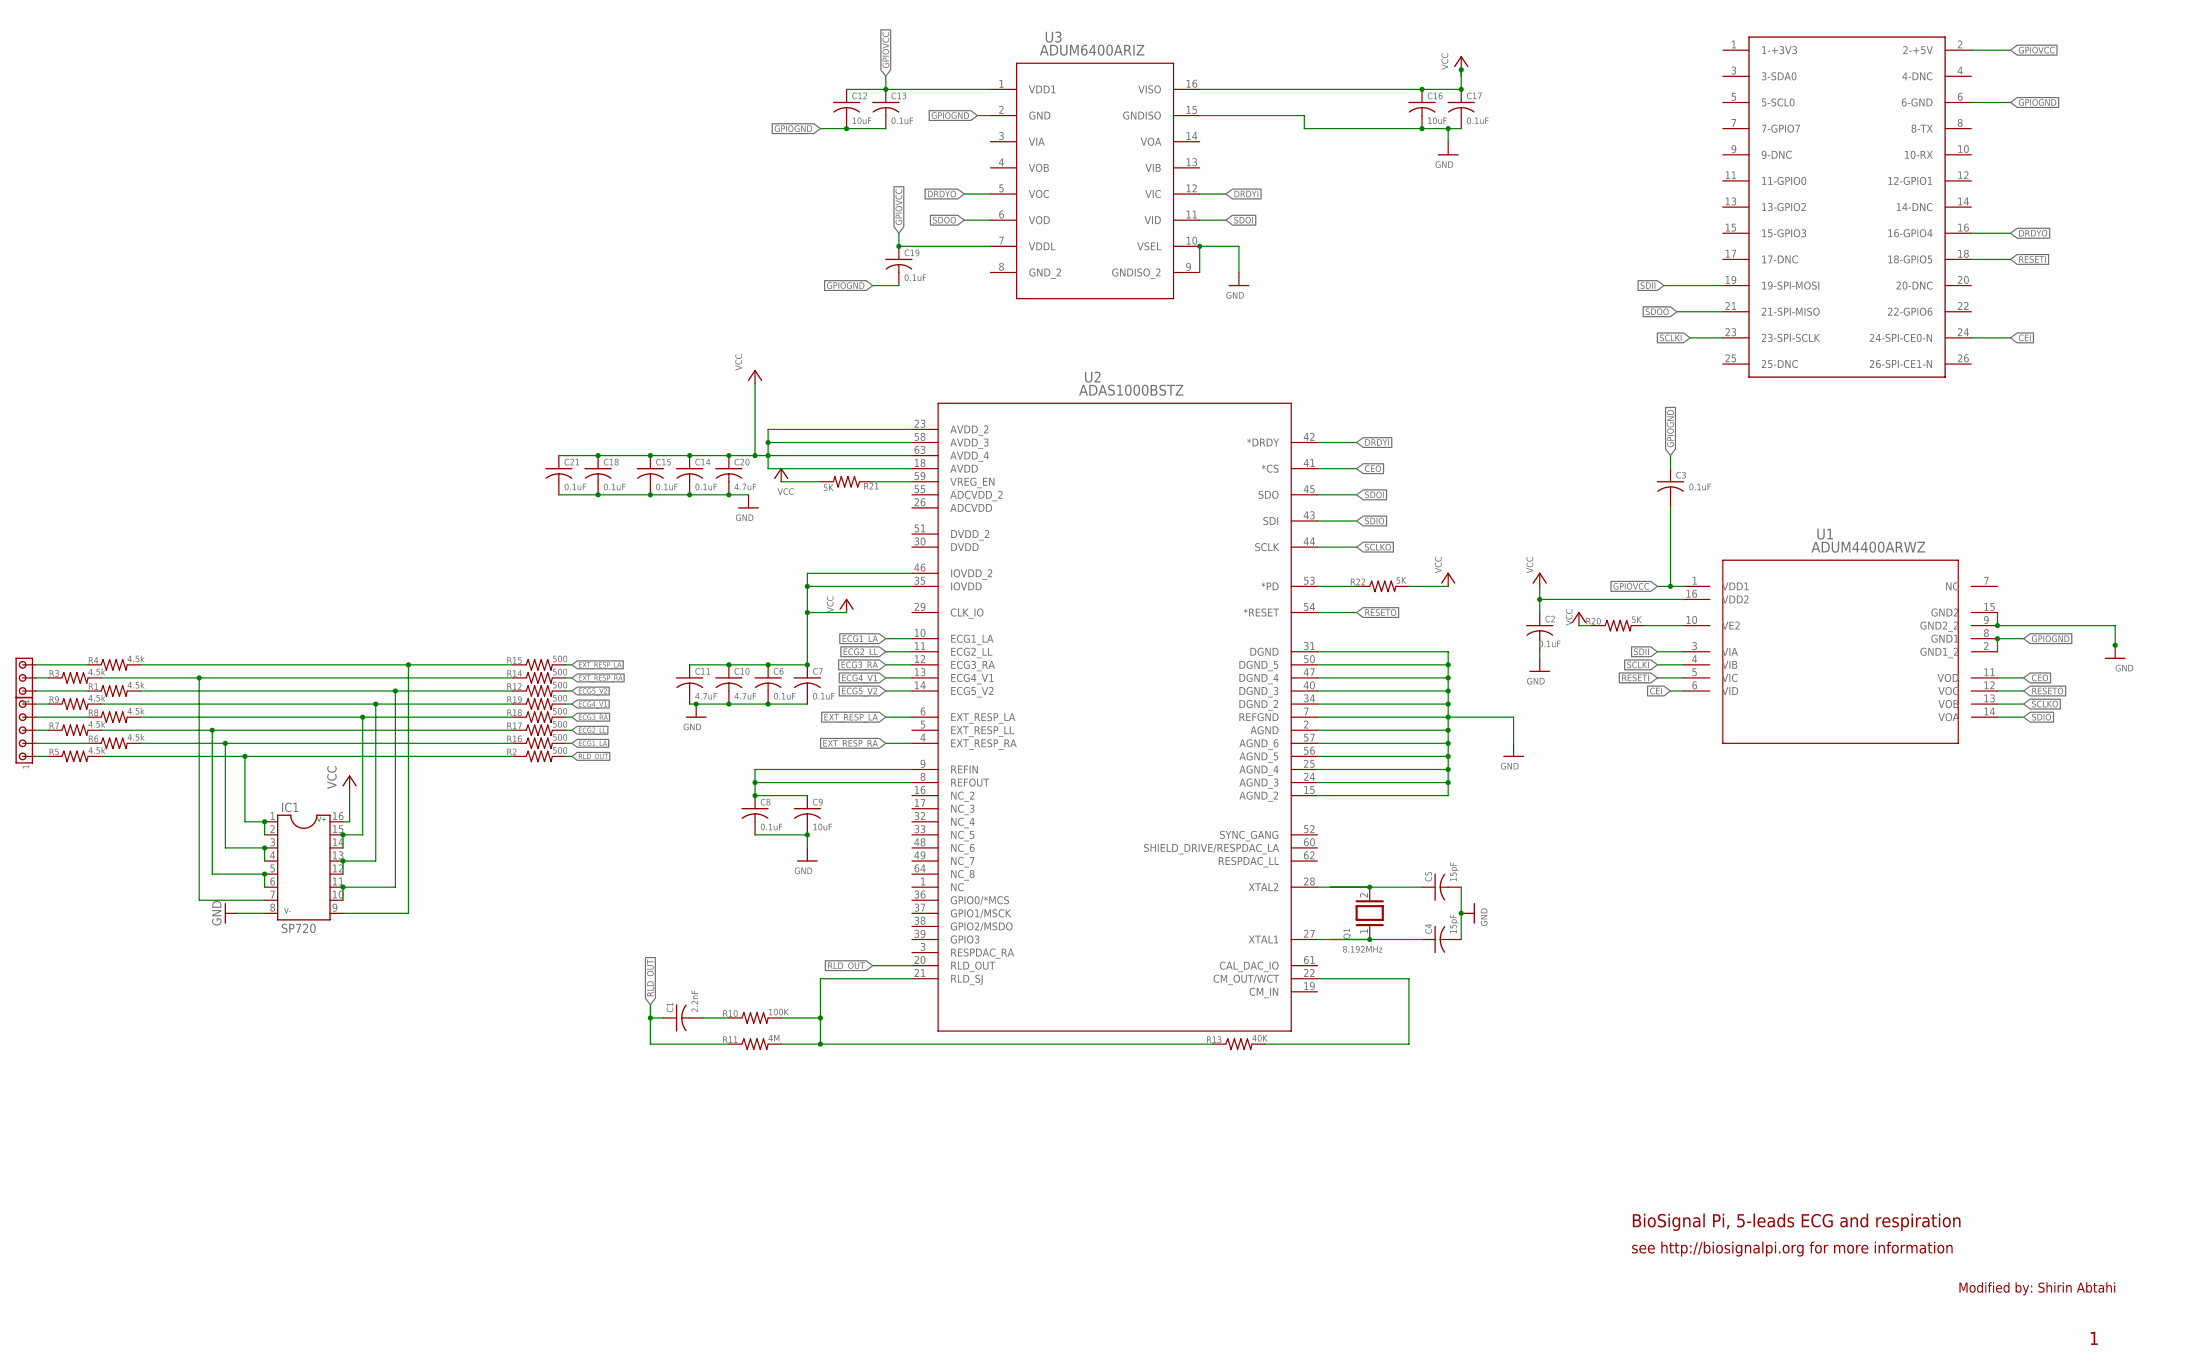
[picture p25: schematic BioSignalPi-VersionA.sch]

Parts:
C1: 2.2nF; C0805
C2, C3, C6, C7, C8, C13, C14, C15, C17, C18, C19, C21: 0.1uF; C0805
C4, C5: 15pF; C0805
C9, C12, C16: 10uF; C0805
C10, C11, C20: 4.7uF; C0805
IC1: SP720; DIL16
J1: JUMPERS; 10X03MTA
J2: JUMPERS; 10X05MTA
Q1: 8.192MHz; QS
R1, R3, R4, R5, R6, R7, R8, R9: 4.5k; R0805
R2, R12, R14, R15, R16, R17, R18, R19: 500; R0805
R10: 100K; R0805
R11: 4M; R0805
R13: 40K; R0805
R20, R21, R22: 5K; R0805
U1: ADUM4400ARWZ; RW_16
U2: ADAS1000BSTZ; ST_64_2
U3: ADUM6400ARIZ; RI_16_1
U$1: RASPBERRY-PI

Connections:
CEI: U1.6 (VID), U$1.24 (24-SPI-CE0-N)
CEO: U1.11 (VOD), U2.41 (*CS)
DRDYI: U2.42 (*DRDY), U3.12 (VIC)
DRDYO: U3.5 (VOC), U$1.16 (16-GPIO4)
ECG1_LA: R16.2, U2.10 (ECG1_LA)
ECG2_LL: R17.2, U2.11 (ECG2_LL)
ECG3_RA: R18.2, U2.12 (ECG3_RA)
ECG4_V1: R19.2, U2.13 (ECG4_V1)
ECG5_V2: R12.2, U2.14 (ECG5_V2)
EXT_RESP_LA: R15.2, U2.6 (EXT_RESP_LA)
EXT_RESP_RA: R14.2, U2.4 (EXT_RESP_RA)
GND: C2.2, C4.2, C5.2, C6.2, C7.2, C8.2, C9.2, C10.2, C11.2, C14.2, C15.2, C16.2, C17.2, C18.2, C20.2, C21.2, IC1.8, U1.9 (GND2_2), U1.15 (GND2), U2.2 (AGND), U2.7 (REFGND), U2.15 (AGND_2), U2.24 (AGND_3), U2.25 (AGND_4), U2.31 (DGND), U2.34 (DGND_2), U2.40 (DGND_3), U2.47 (DGND_4), U2.50 (DGND_5), U2.56 (AGND_5), U2.57 (AGND_6), U3.9 (GNDISO_2), U3.10 (VSEL), U3.15 (GNDISO)
GPIOGND: C3.1, C12.2, C13.2, C19.2, U1.2 (GND1_2), U1.8 (GND1), U3.2 (GND), U$1.6 (6-GND)
GPIOVCC: C3.2, C12.1, C13.1, C19.1, U1.1 (VDD1), U3.1 (VDD1), U3.7 (VDDL), U$1.2 (2-+5V)
JUMPERS: J1.1, R1.1
unnamed: J2.1, R5.1
unnamed: J2.2, R6.1
unnamed: J2.3, R7.1
unnamed: J2.4, R8.1
unnamed: J2.5, R9.1
unnamed: J1.2, R3.1
unnamed: J1.3, R4.1
unnamed: IC1.9, R4.2, R15.1
unnamed: IC1.7, R3.2, R14.1
unnamed: C5.1, Q1.2, U2.28 (XTAL2)
unnamed: C4.1, Q1.1, U2.27 (XTAL1)
unnamed: R10.2, R11.2, R13.1, U2.21 (RLD_SJ)
unnamed: IC1.1, IC1.2, R2.1, R5.2
unnamed: IC1.14, IC1.15, R8.2, R18.1
unnamed: IC1.12, IC1.13, R9.2, R19.1
unnamed: IC1.3, IC1.4, R6.2, R16.1
unnamed: IC1.5, IC1.6, R7.2, R17.1
unnamed: IC1.10, IC1.11, R1.2, R12.1
unnamed: R20.2, U1.10 (VE2)
unnamed: R22.1, U2.53 (*PD)
unnamed: R13.2, U2.22 (CM_OUT/WCT)
unnamed: C1.2, R10.1
unnamed: R21.1, U2.59 (VREG_EN)
unnamed: C8.1, C9.1, U2.8 (REFOUT), U2.9 (REFIN)
RESETI: U1.5 (VIC), U$1.18 (18-GPIO5)
RESETO: U1.12 (VOC), U2.54 (*RESET)
RLD_OUT: C1.1, R2.2, R11.1, U2.20 (RLD_OUT)
SCLKI: U1.4 (VIB), U$1.23 (23-SPI-SCLK)
SCLKO: U1.13 (VOB), U2.44 (SCLK)
SDII: U1.3 (VIA), U$1.19 (19-SPI-MOSI)
SDIO: U1.14 (VOA), U2.43 (SDI)
SDOI: U2.45 (SDO), U3.11 (VID)
SDOO: U3.6 (VOD), U$1.21 (21-SPI-MISO)
VCC: C2.1, C6.1, C7.1, C10.1, C11.1, C14.1, C15.1, C16.1, C17.1, C18.1, C20.1, C21.1, IC1.16, R20.1, R21.2, R22.2, U1.16 (VDD2), U2.18 (AVDD), U2.23 (AVDD_2), U2.35 (IOVDD), U2.46 (IOVDD_2), U2.58 (AVDD_3), U2.63 (AVDD_4), U3.16 (VISO)

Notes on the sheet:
BioSignal Pi, 5-leads ECG and respiration
see http://biosignalpi.org for more information
Modified by: Shirin Abtahi

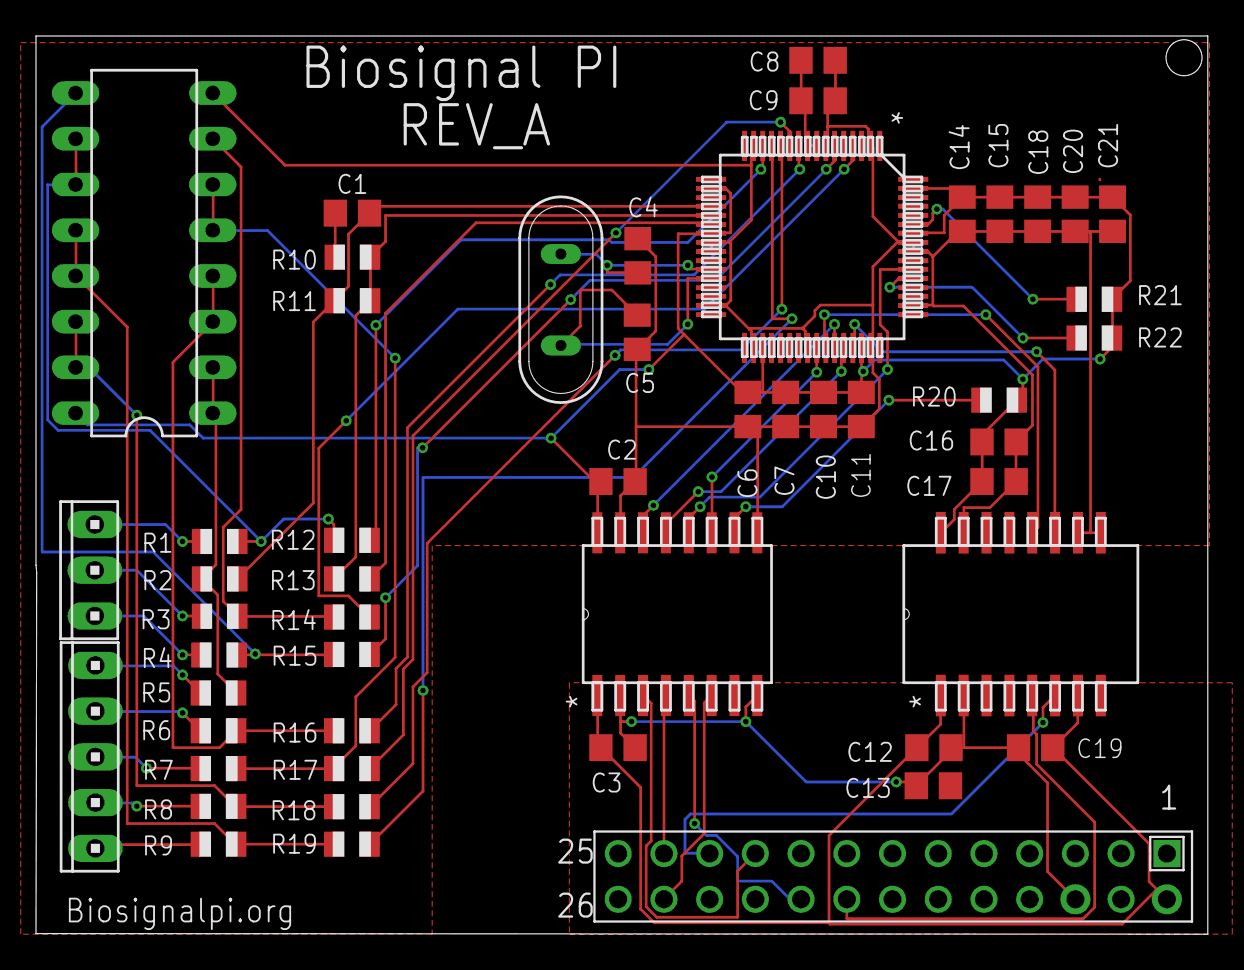
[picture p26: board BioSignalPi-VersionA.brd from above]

Board: 2 copper layers, 65.1 x 49.9 mm, 51 parts (0 on the bottom side), 49 nets.
